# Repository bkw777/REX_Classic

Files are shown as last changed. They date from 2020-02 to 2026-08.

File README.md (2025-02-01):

# REX Classic, BKW re-spin
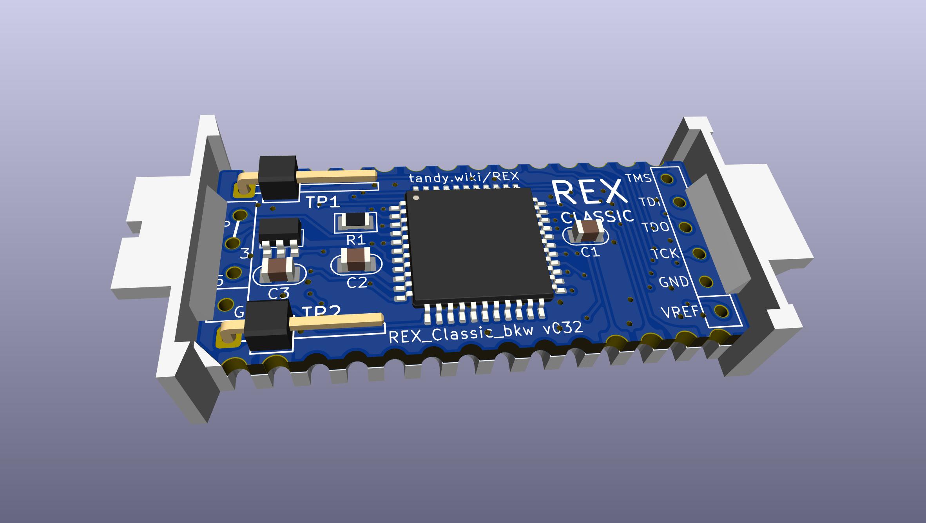
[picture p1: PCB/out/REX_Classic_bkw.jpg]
  
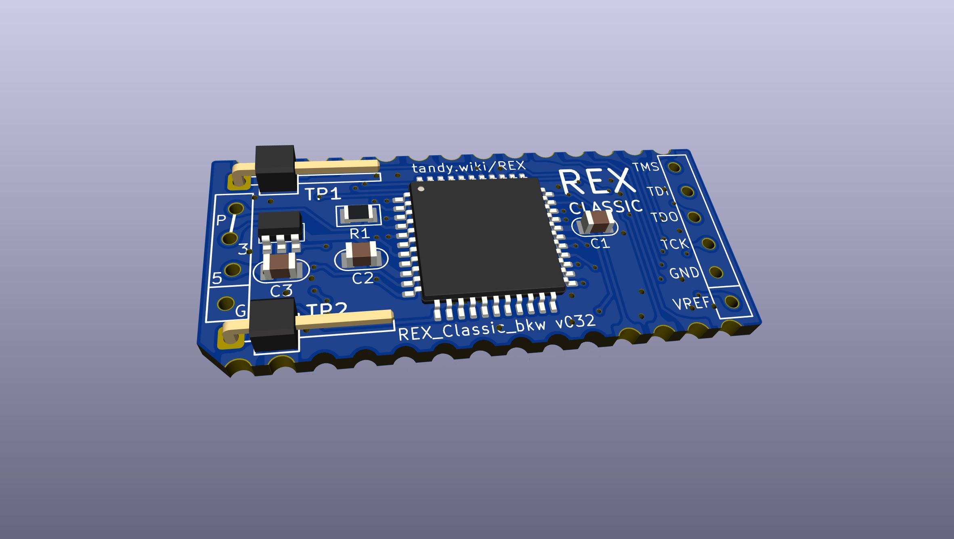
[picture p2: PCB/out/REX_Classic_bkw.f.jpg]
  
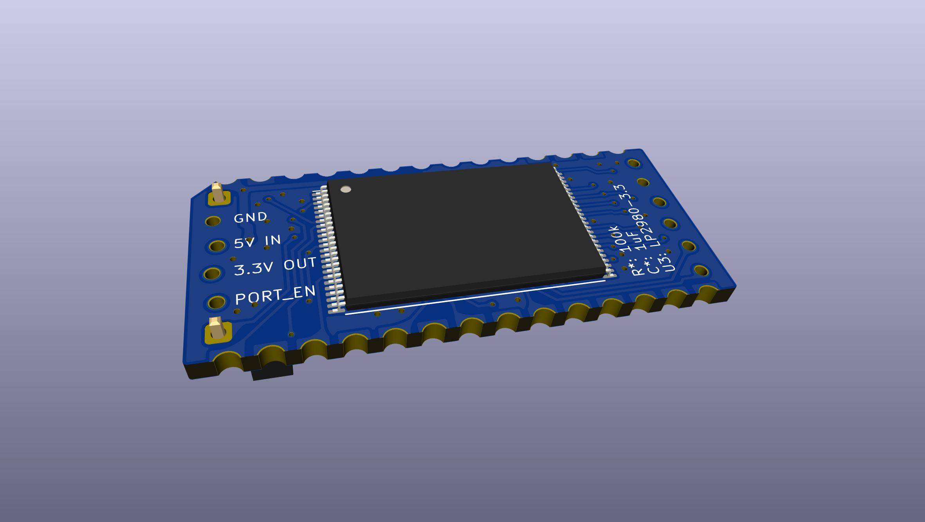
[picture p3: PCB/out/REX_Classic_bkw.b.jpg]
  
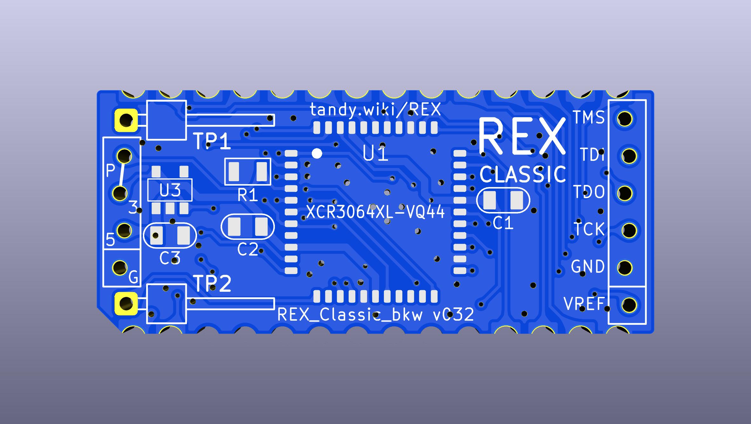
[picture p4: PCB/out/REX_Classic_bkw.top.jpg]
  
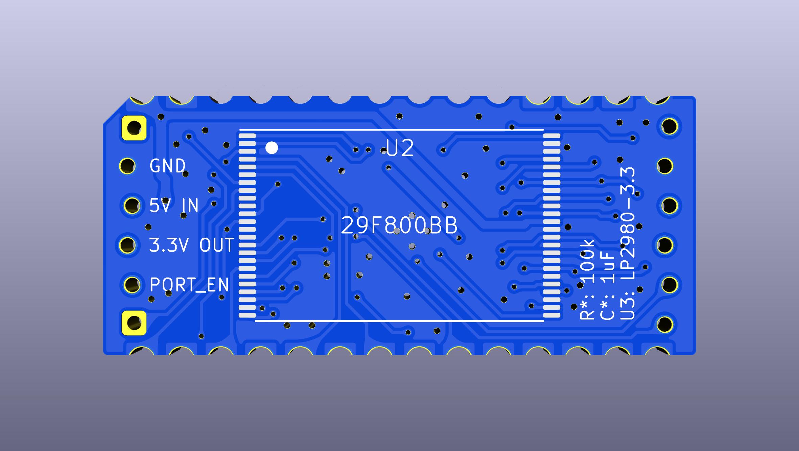
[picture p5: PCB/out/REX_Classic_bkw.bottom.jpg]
  
  

### Directions
http://tandy.wiki/REX

Gerbers & cpld bitstream in [releases](../../releases/latest).

BOM: [DigiKey](https://www.digikey.com/short/zwwvvr2j)  
PCB & Carrier: [PCBWAY](https://www.pcbway.com/project/shareproject/REX_Classic__BKW_re_spin.html)

Ordering tips for the pcb & carrier:  
* on PCBWAY manually change the min tracks/spaces to 6mil/6mil
* For gold contacts, select ENIG copper finish
* For the carrier select material Nylon, process SLS
* PCBWAY is more expensive, especially for ENIG, and they don't have the best print option for the carrier.
  Elecrow is cheaper for ENIG, and their "High Strength Nylon" option for 3d printing is actually black nylon printed by MJF, which is the nicest for this.
  It's just that on Elecrow you have to upload the gerber zip and carrier stl from [releases](../../releases/latest), there is no pre-configured buy page.

Carrier cad source: https://github.com/bkw777/Molex78802_Module (PCB_28 variant)

### Original REX design is by Steven Adolph
http://bitchin100.com/wiki/index.php?title=REX  
http://www.club100.org/memfiles/index.php?direction=0&order=&directory=Steve%20Adolph

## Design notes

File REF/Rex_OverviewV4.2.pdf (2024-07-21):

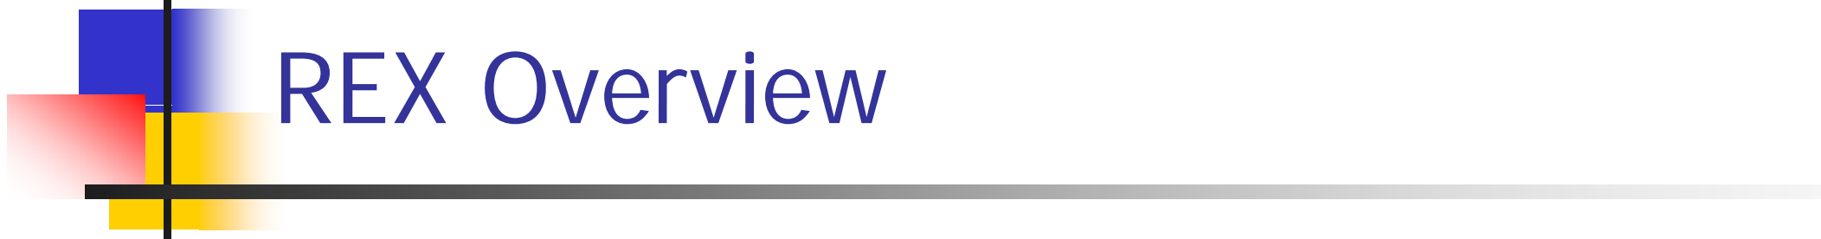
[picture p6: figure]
REX Overview

Initial Release
Steve Adolph
Oct 2008

## What is REX?

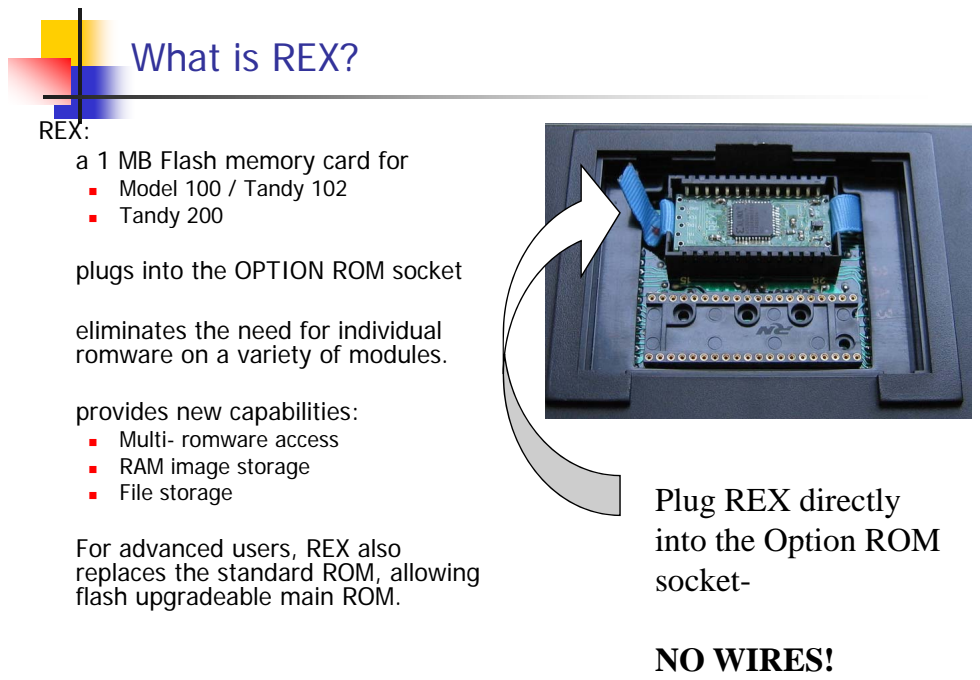
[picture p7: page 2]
Model 100 / Tandy 102; Tandy 200; - romware access; RAM image storage; File storage; For advanced users, REX also; into the Option ROM; socket-; NO WIRES!

REX:
a 1 MB Flash memory card for
plugs into the OPTION ROM socket

eliminates the need for individual
romware on a variety of modules.
provides new capabilities:
replaces the standard ROM, allowing
flash upgradeable main ROM.

Plug REX directly

## How it works

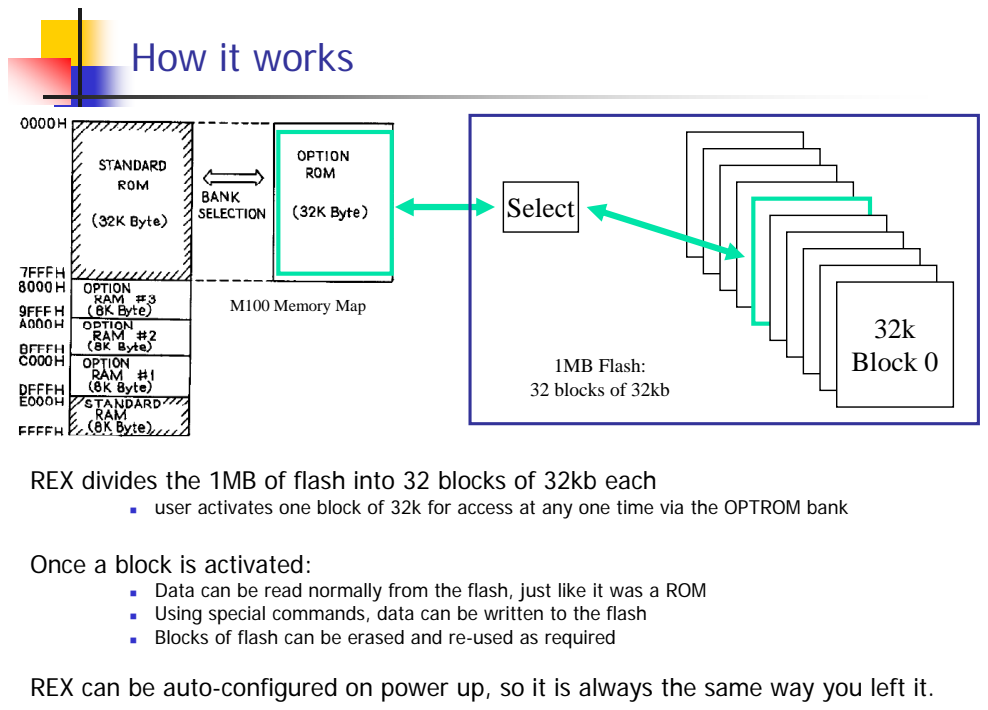
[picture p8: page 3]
Select; M100 Memory Map; 1MB Flash:; Block 0; 32 blocks of 32kb; user activates one block of 32k for access at any one time via the OPTROM bank; Data can be read normally from the flash, just like it was a ROM; Using special commands, data can be written to the flash; Blocks of flash can be erased and re-used as required

REX divides the 1MB of flash into 32 blocks of 32kb each

Once a block is activated:

REX can be auto-configured on power up, so it is always the same way you left it.

## REX Architecture

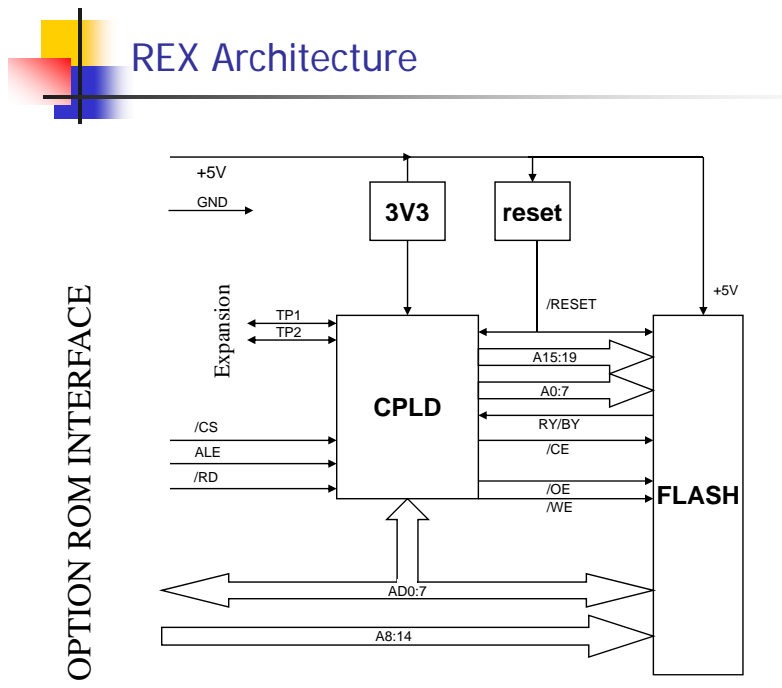
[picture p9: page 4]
+5V reset GND; /RESET; CE TP1 nsion; TERFATP2 Expa; ROM I; PTION

A15:19 A0:7 CPLD /CS RY/BY

/CE ALE /RD /OE /WE | FLASH

## REX Physical Specifications

Physical Dimensions
To fit within OPTION ROM socket

FLASH
| 1MB AM29F800B 5V FLASH
| Xilinx Coolrunner XCR3064XL-10VQ44

Power Supplies
| CPLD: LP2980 (3.3 fixed, derived from system +5V)
| FLASH: system +5V (external to REX)

Power Consumption
Negligible during reads, TBD during writes

## REX Memory Assignment

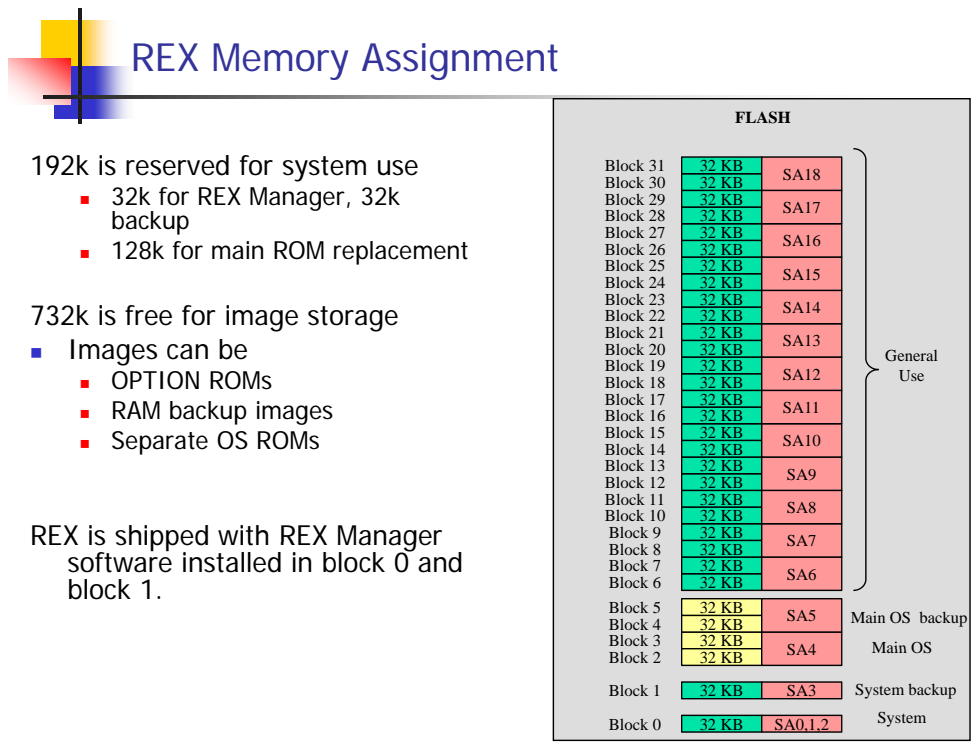
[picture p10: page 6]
32k for REX Manager, 32k; backup; Block 28; Block 29; Block 30; Block 31; FLASH

192k is reserved for system use

 128k for main ROM replacement 732k is free for ima ge stora g e | Block 27 32 KB SA16 Block 26 32 KB Block 25 32 KB SA15 Block 24 32 KB Block 23 32 KB SA14 Block 22 32 KB

 Images can be  OPTION ROMs  RAM backup images  Sepa rate OS ROMs | Bloc k 21 32 KB SA13 Block 20 32 KB General Block 19 32 KB SA12 Use Block 18 32 KB Block 17 32 KB SA11 Block 16 32 KB Block 15 32 KB

REX is shipped with REX Manager | SA10 Block 14 32 KB Block 13 32 KB SA9 Block 12 32 KB Block 11 32 KB SA8 Block 10 32 KB 32 KB Block 9 SA7 SA7

software installed in block 0 and block 1. | Block 8 32 KB Block 7 32 KB SA6 Block 6 32 KB Block 5 32 KB SA5 Main OS backup Block 4 32 KB Block 3 32 KB SA4 Main OS Main OS SA4

Block 2 32 KB System backup Block 1 32 KB SA3 System Block 0 32 KB SA0,1,2

## REX2 Architecture

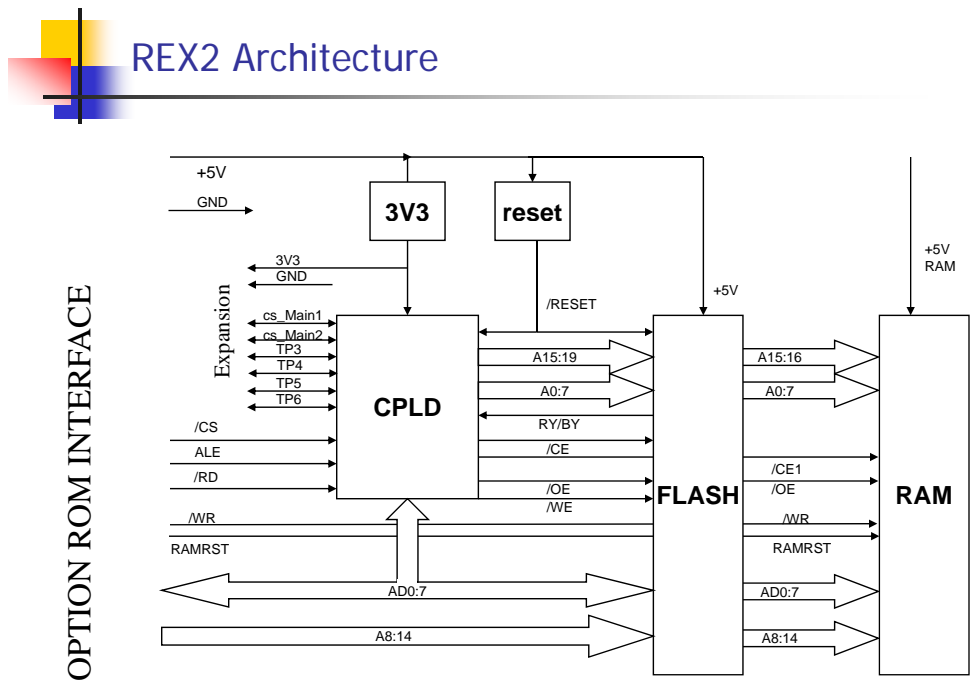
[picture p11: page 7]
+5V reset GND; /RESET; +5V RAM; cs_Main1; 3V3 GND; nsion; TERFATP3 TP4 cs_Main2 TP5 TP6; Expan

A15:19 A0:7 CPLD /CS RY/BY | A15:16 A0:7

ROM IN RAM /WR /WR

/CE ALE /RD /OE /WE | /CE1 /OE FLASH

PTION RAMRST RAMRST

## REX2 Physical Specifications

Physical Dimensions
| To fit within option rom socket
| 1MB AM29F800B 5V FLASH

CPLD
Xilinx Coolrunner XCR3064XL-10VQ44

RAM (REX2 only)
Toshiba TC551001 5V SRAM

Power Supplies
CPLD: LP2980 (3.3 fixed)

Power Consumption
Negligible during reads, TBD during writes

REX2 Memory Assignment | SRAM

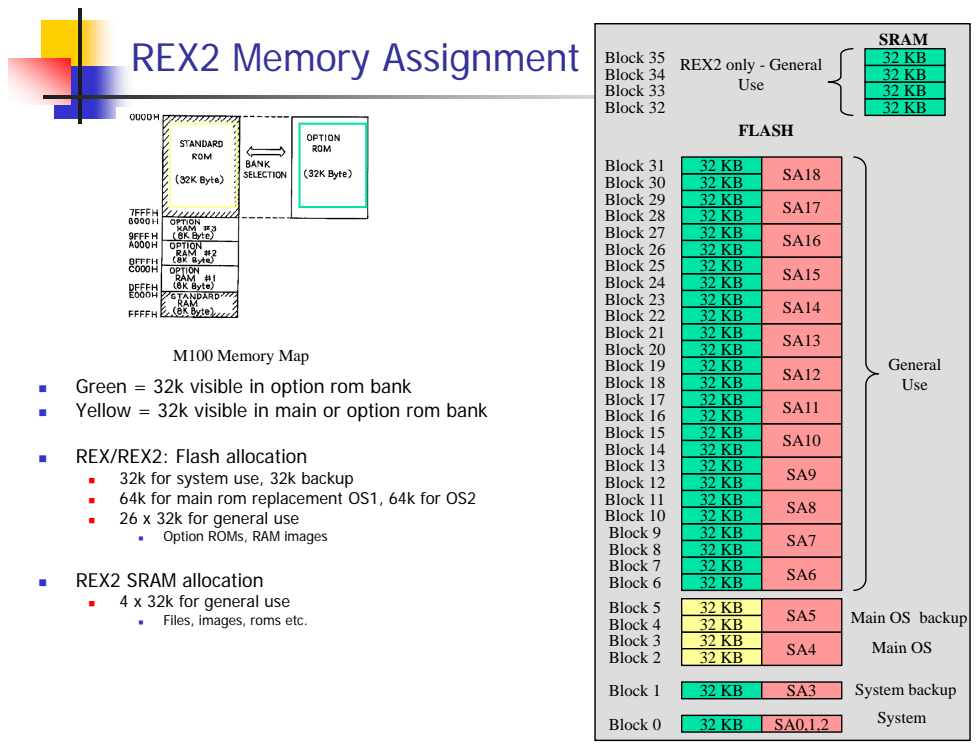
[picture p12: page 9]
Use

Block 35 REX2 only - General
Block 34
Block 33
Block 32

FLASH Block 31 32 KB SA18 Block 30 32 KB Block 29 32 KB SA17 Block 28 32 KB

Block 27 32 KB SA16 Block 26 32 KB Block 25 32 KB SA15 Block 24 32 KB Block 23 32 KB SA14 Block 22 32 KB

M100 Memory Map  Green = 32k visible in option rom bank  Yellow = 32k visible in main or option rom bank | Bloc k 21 32 KB SA13 Block 20 32 KB General Block 19 32 KB SA12 Block 18 32 KB Use Block 17 32 KB SA11 Block 16 32 KB Block 15 32 KB

 REX/REX2: Flash allocation  32k for system use, 32k backup  64k for main rom replacement OS1, 64k for OS2  26 x 32k for general use ges  O ption ROMs, RAM ima | SA10 Block 14 32 KB Block 13 32 KB SA9 Block 12 32 KB Block 11 32 KB SA8 Block 10 32 KB Block 9 32 KB SA7 SA7

 REX2 SRAM allocation  4 x 32k for general use  Files, images, roms etc. | Block 8 32 KB Block 7 32 KB SA6 Block 6 32 KB Block 5 32 KB SA5 Main OS backup Block 4 32 KB Block 3 32 KB SA4 Main OS Main OS SA4

Block 2 32 KB System backup Block 1 32 KB SA3 System Block 0 32 KB SA0,1,2

## The ACTIVE block

What is the ACTIVE Block?
Any of the 32 blocks of flash memory can be “active” – that means that the block is currently visible in the option ROM bank.
When a block is “active”, the 32k binary image stored in that block looks exactly as if an option ROM with that image was plugged in.
In this way REX allows the user to have access to all 1MB of the flash chip

Setting or changing the ACTIVE Block:
The user can define what block is “active” IE “in use”, using the integrated REX Manager software.

POWER UP:
| When the laptop is powered up, REX defaults to block 0 always.
| Auto-activation: REX installs some special software in the laptop that
redirects the power up routines to REX Manager, which searches for the
active block and sets it up for the user on every power up , | .

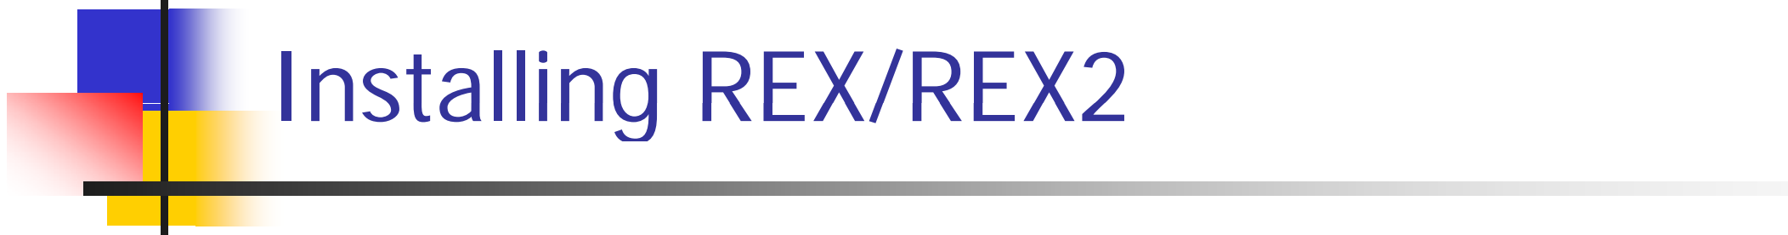
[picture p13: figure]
Installing REX/REX2

## Installing REX

REX installs in the OPTION ROM socket just like any other ROM.

Three things are supplied with REX -
| REX card
| Ribbon (used to extract REX if need be)
| Balsa spacer (used to guarantee REX seats properly in the socket Balsa spacer (used to guarantee REX seats properly in the socket

## Installing REX: Step 1

Insert balsa spacer gently GENTLY into the OPTION ROM socket. You may have to press against the springy contacts of the socket to get the spacer to sit flat against the bottom of the socket.

## Installing REX: Step 2

Lay the ribbon on top of the balsa spacer such that it is evenly centered in the socket, and the tails of the ribbon are even on both sides of the socket.

## Installing REX: Step 3

REX is placed in the ROM socket with the flash chip hidden, and the CPLD visible. You must orient REX correctly inside the socket. Look closely at the OPTROM socket, and you will see that one end of the socket has a single vertical notch in the center of one end, and the other has a dual vertical notch.

## Installing REX: Step 3

REX has a single white dash marking on the CPLD side on one end (opposite end from the row of six holes). This end (which also has 2 holes marked TP1 and TP2) must line up with the single notch of the socket, such that the white dash marking lines up with the single notch.

## Installing REX: Step 3

Once you understand how REX needs to be oriented in the socket, gently place REX into the OPTROM socket so that it is resting evenly on the springy contacts. Now, firmly press REX downward so that it evenly and flatly sits on top of the spacer and the ribbon, and all springy contacts are evenly contacting REX.

## Initializing REX

To initialize the environment, REX Manager’s initialization routine must be started. The initialization sequence is as follows-

First, REX Manager boot up software is installed.
| This software uses the timer hook to re-direct every power up to the REX Manager application
| This allows the active block to be detected and provisioned automatically
| A hidden file RXHOOK is inj ected as the first basic program
| REXMGR.BA is injected, and allows manual starting of REX Manager

Initialization from a COLD RESTART: Initialization from a COLD RESTART:
| Enter BASIC
| Type
| CALL 63012 <enter>
| You will be directed to the initialization routine

Re-initializing the environment (if needed):
| Everytime REX Manager runs it verifies that it is properly installed Everytime REX Manager runs, it verifies that it is properly installed, and it re-installs all files and the timer hook settings needed.

## Starting REX Manager

Starting REX Manager:
| Load and run the basic program REXMGR.BA
| You will be directed to REX Manager

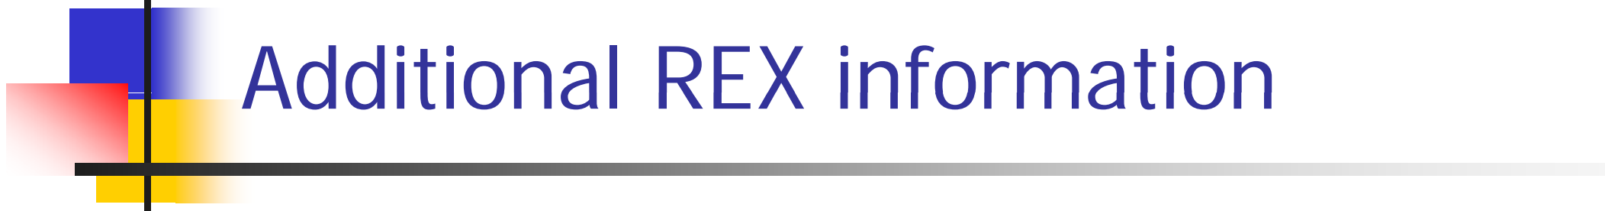
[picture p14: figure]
Additional REX information

## REX Registers

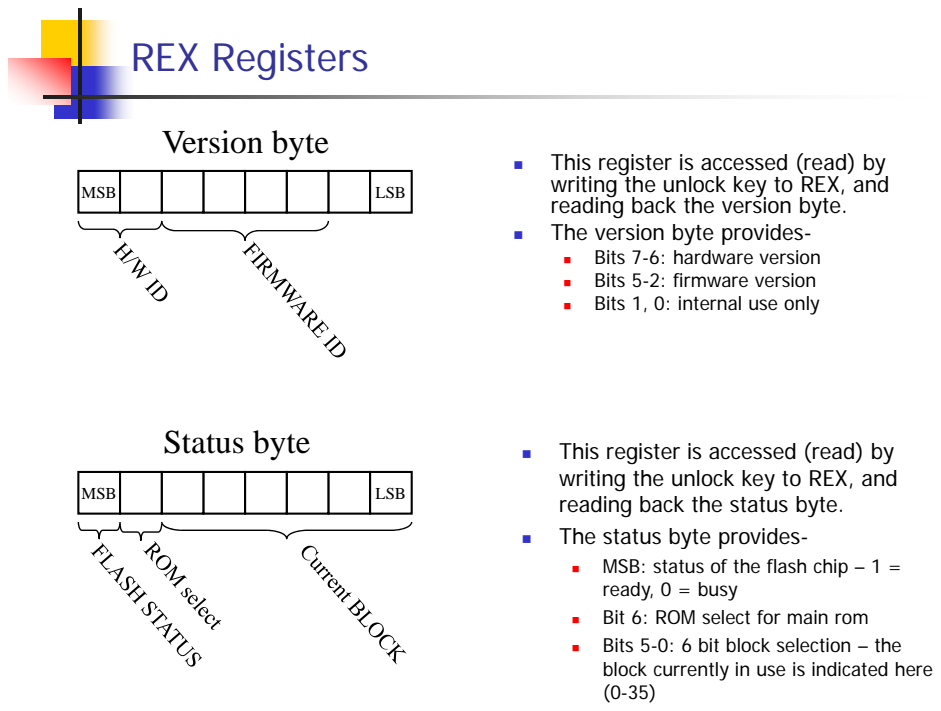
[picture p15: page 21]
This register is accessed (read) by; reading back the version byte. MSB; LSB; Version byte; The version byte provides-; Bits 7-6: hardware version; Bits 5-2: firmware version; Bits 1, 0: internal use only; MSB; The status byte provides-; Status byte; MSB: status of the flash chip – 1 =; Bit 6: ROM select for main rom; Bits 5-0: 6 bit block selection – the

writing the unlock key to REX, and

reading back the status byte.
ready, 0 = busy
block currently in use is indicated here

## REX state machine

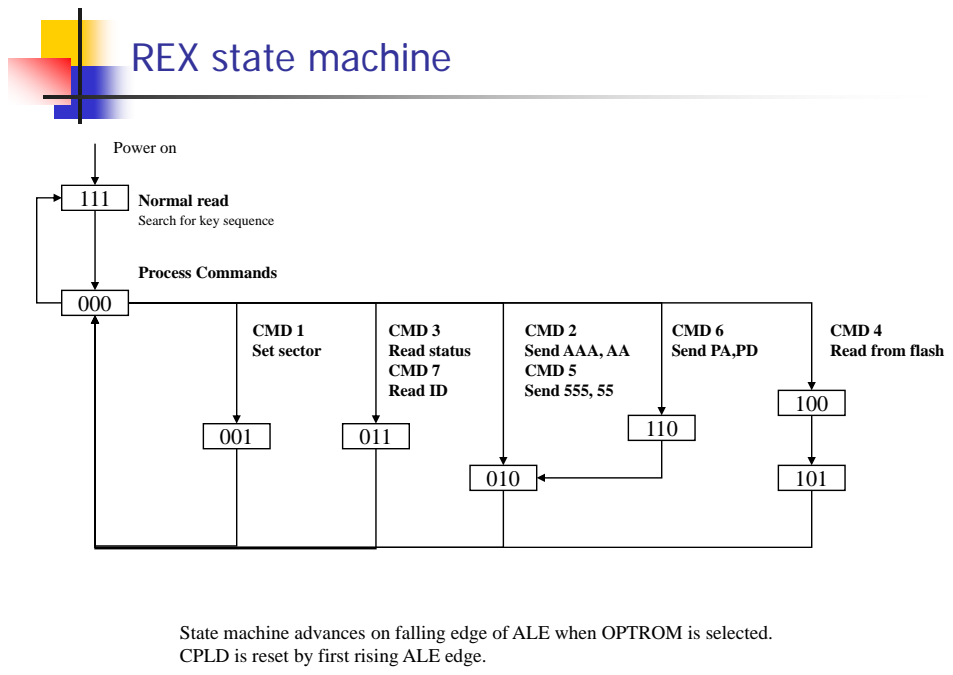
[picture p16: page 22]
Power on; CMD 1; Process Commands; CMD 3; CMD 2; CMD 6; CMD 4; CMD 1 Set sector; CMD 3 Read status CMD 7 Read ID

Normal read
Search for key sequence

CMD 2
Send AAA, AA
CMD 5
Send 555, 55

CMD 6
Send PA,PD

CMD 4
Read from flash

State machine advances on falling edge of ALE when OPTROM is selected.
CPLD is reset by first rising ALE edge.

## REX Manager software

REX has it’s own management software built in – REX Manager
| This software is provided as a option rom, and is loaded into the default power up block, block 0.
| It is also backed up into block 1.
| REX Mana ger comes in 2 versions – M100/T102 and T200 – they are not interchangeable, however one may reprogram the software to suit.

REX Manager (Release 4.2) supports
| Select – user identifies a block to process
| Activate – user identifies a block to be “in use”
| Copy – copy an image from “selected” block to another block
| Erase – erases the “selected” block
| Program – programs the “selected” block from a 32k binary file stored on TPDD
| Name – assign a name to the “selected” block

REX Mana

g er kee

ps track of the “active” block in a 1kb directory, and the names of all the blocks in another 3kb directory.
| Directories are stored in block 0, backed up in block 1.
| 1000 active block assignments can be made before the directory needs to be rebuilt
| 368 block name assignmen ts can be ma de b e fore the directory nee ds to be rebuilt
| Directory rebuilding is an automatic function, transparent to the user.

## Flash organization

The AM29F800B flash chip is designed with 19 SECTORS
A sector is defined as an independent, erasable area within the flash
The entire chip can be erased, or a single sector can be erased sector can be erased
| There are 4 small sectors
| SA0 – 16 kbytes
| SA1 – 8 kbytes
| SA2 – 8 kbytes
| SA3 – 32 kbytes
| The remaining sectors are 64 kbytes
| This poses a challenge to the M100 user.
A rom image is typically 32kb, but the sector size is 64 kb. So, erasing one 32k block requires erasing another adjacent block requires erasing another adjacent 32k block, and re-writing the contents later.
| In general, to program a rom, one must
| Copy the other ½ of the sector to
another sector
| Erase the sector
| Program the new rom image to half of
the sector
Reprogram the other half of the sector

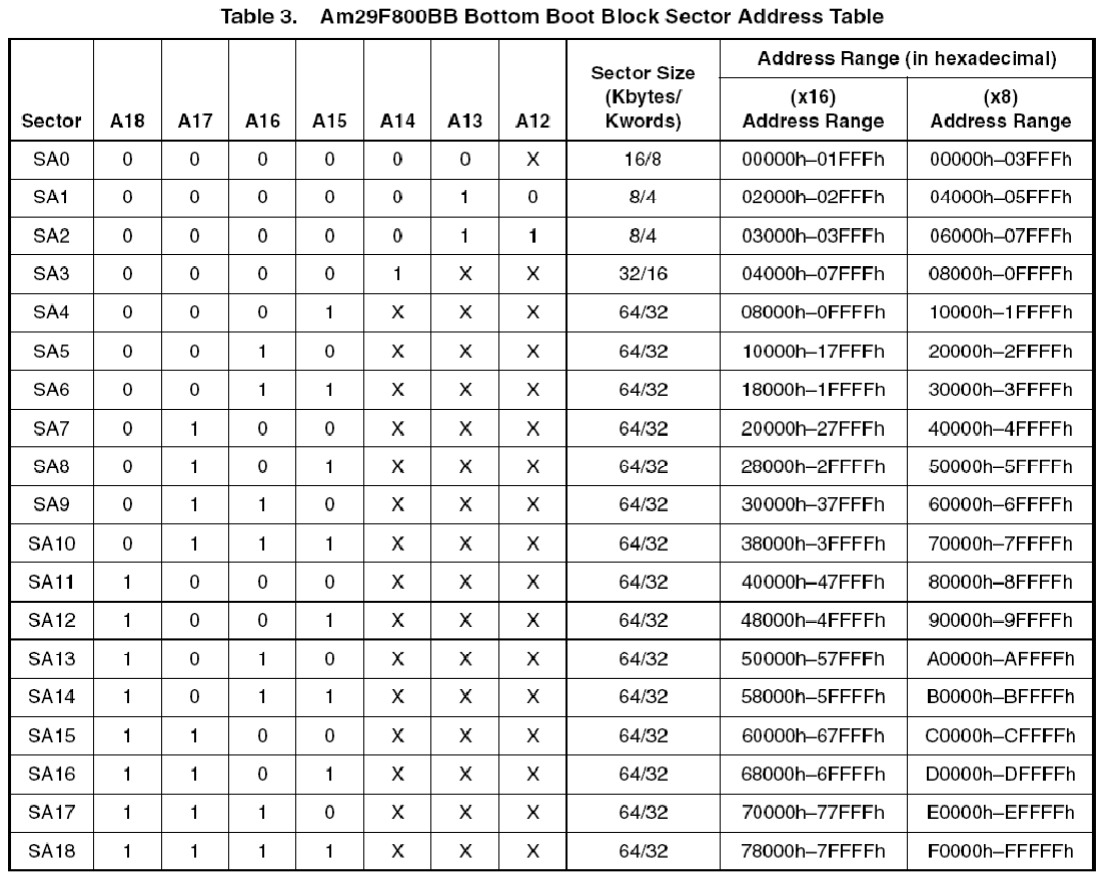
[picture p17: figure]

SECTOR == memory regions defined in flash device

BLOCK == a 32 kbyte region mapped into the option rom memory usable by the laptop rom memory, usable by the laptop

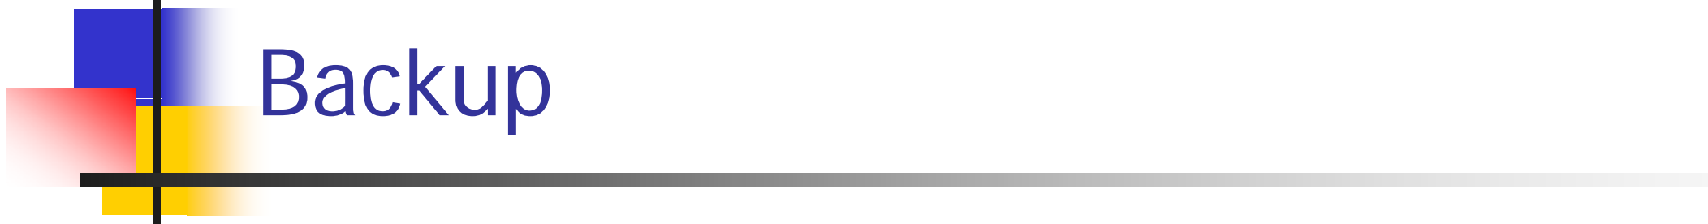
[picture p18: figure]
Backup

## REX vs. REX2

REX (available now) has a single 1 MB flash chip.

## REX2 (not available yet) incorporates a 128 KB

static RAM chip as well as the 1MB flash chip.
This increases the # of blocks from 32 to 36 (blocks 33-36 are SRAM).

## Benefits:

Additional memory for general use
Supports all-ram operation (CP/M!) Supports ram based file storage.

## SRAM access in REX2 requires installation of 3 additional wires

Vram, /WR and RAMRST

## REX Installation Levels

## LEVEL 1: Wire Free basic installation

| Standard installation, all base features
| Simple plug an

d play install
Valid for all firmware codes

## LEVEL 2: ROM Replacement

| Allows the main rom to be provided by REX
| Re

q uires 1

(M100/T102) or 2

(T200) wires to be installed
| The original main rom(s) must be removed or disabled
| On M100/T200, the rom chip(s) can simply be unplugged
| On T102, the rom chip must be removed or disabled

## REX2 Overview

REX2 is a FLASH card that plugs into the option rom socket on M100, T102 and T200 laptops.

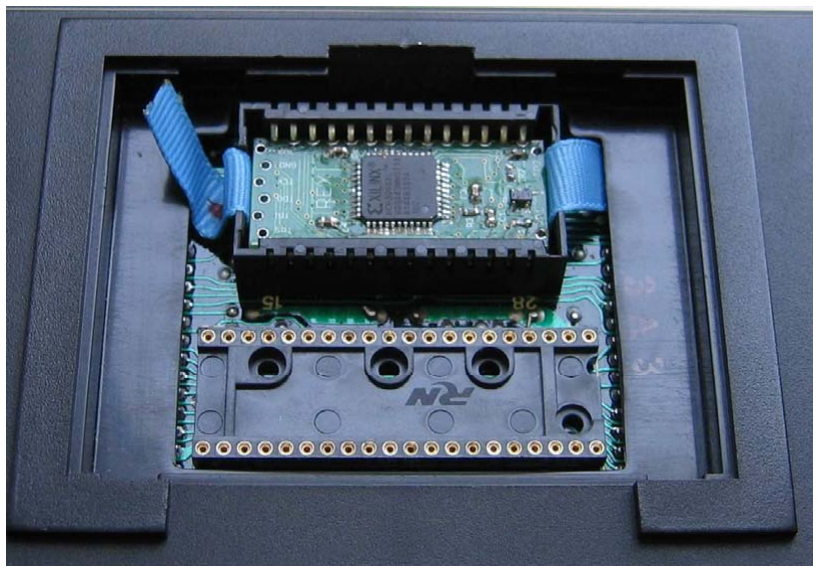
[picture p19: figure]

This upgrade provides Memory expansion via the option ROM bank
| 1 Mb of flash memory 1 Mb of flash memory
| REX2 only: 128 kb of SRAM
| Memory used for
| multiple rom storage
| Flash File storage
| System image backups System image backups
| *Upgradeable main rom
| *Rom development
| *Ram file storage

REX2 also provides an expansion capability
Power/ground + 4 unused I/O

* Level 2 and 3 installation features

## REX Installation Requirements

Model | Level 1 install: Base features | Level 2 install: Rom Replacement | Wires needed
REX | | | No wires needed
REX | | | 1 (M100/T102) 2 (T200)

LEVEL 1: Wire Free basic
installation

LEVEL 2: ROM Replacement
REX provides the main ROMs Two OS images are supported Standard installation, all base features
| Simple plug and play install
| Two OS images are supported
| Requires some hardware modification
| The original main ROM(s) must be
removed or disabled
| - unp lu

g the ROM
| T200 - unplug the ROMs
| T102 - the ROM must be removed or
disabled

## REX Versions

Version 1: REX
| has a CPLD and a flash chip for a total of 2 ICs
| Hardware ID = 00

Version 2: REX2
| has a CPLD, a flash chip, and an SRAM chip for a total of 3 ICs
| hardware ID = 01

Each REX has a CPLD firmware load
| Firmware ID is a 6 bit value
| Readable from the REX version byte Readable from the REX version byte
| Firmware is not upgradable by the user, but it can be upgraded by returning it.

Can be used in either M100/T102 or T200
| Each REX can be shipped with a software load for either M100/T102 or T200
| The software load contains all the utilities and functions needed to operate REX.
| User can change or upgrade this load by using a special utility

## ROM Replacement

If level 2 installation is done, a valid ROM image MUST be present in block 2/3 to boot the machine
| If this block is somehow corrupted, then REX cannot boot the machine.
| There is no emergency safeguard to having a bad image burned
| Once the process to update block 2/3 is started, there is no way to
detect and take action for a bad burn detect and take action for a bad burn

In the event of a corrupt OS preventing boot up, the original main rom needs to be installed again
| This amounts to reverting to a level 1 installation.
| Advanced users could install a switch and pull up inside the ROM
compartment such that the /CS signal to activate the main rom is either:
| directed to REX, and the main rom CS is pulled high, or
| Directed to the main rom and open circuited to REX (REX has a pullup)
| This would allow a mechanism to safeguard against a non-booting machine.

## REX Installation Levels

## LEVEL 1: Wire Free basic installation

| Standard installation, all base features
| Sim

p le

plu

g and

pla

y install

## LEVEL 2: ROM Replacement

| Additional feature included in firmware
| Allows the main rom to be provided by REX
| Requires 1 (M100/T102) or 2 (T200) wires to be installed

The system rom must be removed or disabled
| On M100/T200, the rom chip can simply be unplugged
| On T102, the rom chip must be removed or disabled.

## LEVEL

## 3: 128kb SRAM up

## gra

d

e
| Advanced feature supported by REX2 only
| Allows SRAM to be accessed via the option rom bank

Three wires must be connected from REX2 to system board (clips provided)

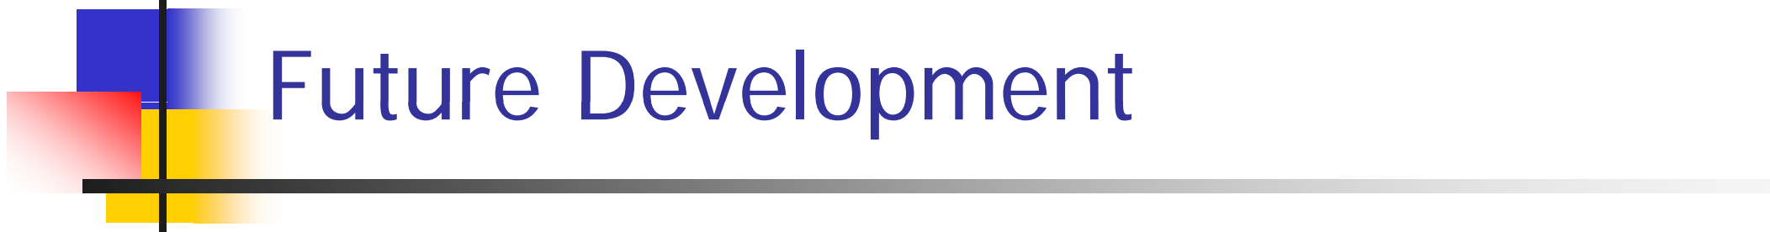
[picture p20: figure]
Future Development

## Flash File System

| Sectors SA0-SA6 are for roms
| Sectors SA7-SA18 are for files
| At least 1 sector must remain free for use as scratchpad
| This leaves 768k – 64k = 704kb as file storage
| Scratchpad allows sectors to be purged of deleted files, and may be used by rom burning routines to copy
blocks
First 1k of every sector used in the file system will be a distributed file directory and block directory
| Need 32 block directory entries, supporting 8 types of blocks
| Type 0: rom binary image block
| Type 1: ram binary image block (M100)
| Type 2: ram binary image block #1 (T200)
| Type 3: ram binary image block #2 (T200)
| Type 4: ram binary image block #3 (T200)
| Type 5: file storage block type 1 (contains directory)
| Type 6: file storage block type 2 (contains only files)
| Type 7: unused/scratchpad
| Byte 00
| Incates sector status
| FF = unused, scratch pad possible
| 00 = in use for file system
| Files will be stored on a 1kb record size similar to RAMPAC
| Files must be contained within a single sector
| This limits file sizes to 32 kb max
| Up to 63 files may be stored in one sector – 693 files max stored in REX
| Directories occupy a directory entry, so directories reduce the # of files per sector

## Flash File System

| Directory entries
| Can be either file names or directory names
| Up to 255 file directories can be named, nesting is supported
| each directory entry is 14 bytes long each directory entry is 14 bytes long
| Byte 0 = type; 0=file, 01-FF = directory number for this record (if not a file)
| Byte 1 = directory membership = number from 0 to FF
| Byte 2 = file type descriptor
| Byte 3,4 = file length
| Bytes 5,6 = undefined
| Bytes 7-12 = filename or directory name
| Bytes 13-14 = extension

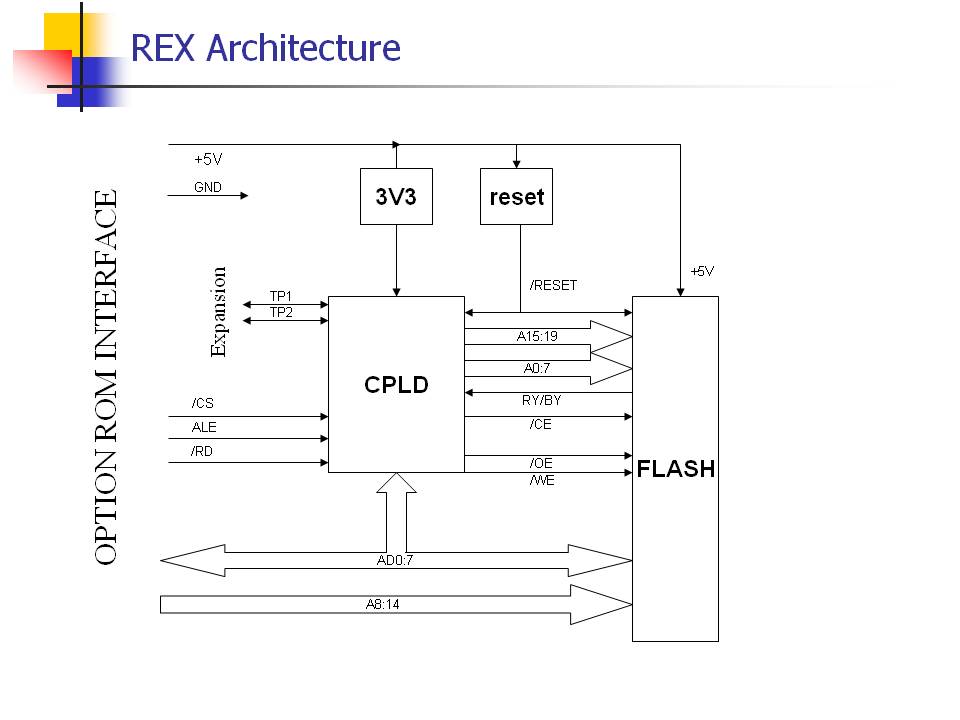
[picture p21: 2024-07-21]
REF/Rex_architecture.jpg

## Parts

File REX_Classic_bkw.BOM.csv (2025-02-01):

Index | Quantity | Part Number | Manufacturer Part Number | Description | Customer Reference | Available | Backorder | Unit Price | Extended Price USD
1 | 1 | 122-1469-ND | XCR3064XL-10VQG44I | IC CPLD 64MC 9.1NS 44VQFP | U1 | 1 | 0 | 12.59000 | 12.59
2 | 10 | A130144CT-ND | CRGCQ0805J47K | RES 47K OHM 5% 1/8W 0805 |  | 10 | 0 | 0.02700 | 0.27
3 | 10 | 399-8001-1-ND | C0805C105J4RACTU | CAP CER 1UF 16V X7R 0805 | C1 | 10 | 0 | 0.18400 | 1.84
4 | 1 | LP2980AIM5X-3.3/NOPBCT-ND | LP2980AIM5X-3.3/NOPB | IC REG LINEAR 3.3V 50MA SOT23-5 | U3 | 1 | 0 | 0.66000 | 0.66
5 | 1 | 1450-M29F800FB5AN6E2-ND | M29F800FB5AN6E2 | IC FLASH 8MBIT PARALLEL 48TSOP I | U2 | 1 | 0 | 4.32000 | 4.32
6 | 1 | 10129379-902002BLF-ND | 10129379-902002BLF | CONN HEADER R/A 2POS 2.54MM | TP1, TP2 | 1 | 0 | 0.10000 | 0.10

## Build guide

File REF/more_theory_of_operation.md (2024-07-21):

(ed: translated from https://bitchin100.com/wiki/index.php?title=REX_Overview)

## REX Overview

REX is a low power 1MB flash card custom designed to work with the Model T.  The challenge for REX is to be able to accomplish a "write" in a socket designed only for "reads".  An additional challenge, is to be able to control 19 address lines and 8 data lines to the flash, with a minimum amount of resources.  

A major challenge with REX, was finding a CPLD with enough I/O to manage the flash, while being small enough to fit in the socket.

## REX Architecture

The architecture of REX is shown in the illustration below.  Here we see that the CPLD (a programmable logic device, the "brains" of REX) sits between the flash chip and the option rom socket connector.  

REX manages only some of the address lines going to the flash - A15-A19, and A0-A7.  A8-A14 are provided as direct connections from the optrom socket, as are AD0-AD7.  REX intercepts the address/data bus AD0-AD7, and the system communicates with the CPLD using data sent on these lines.

Data is sent to REX on the falling edge of the ALE signal.  During this time, the address/data bus AD0-AD7 contains the lower address information for that CPU cycle.

So, in order to send data to REX, the data is sent as the bottom 8 bits of the ADDRESS, not the DATA, during a read cycle from the option rom.

![]Rex_architecture.jpg)

REX needs to distinguish between "normal reads" to the option rom, and "control reads" to REX.  In order to tell them apart, REX listens for a sequence of 6 reads from specific memory locations.  When this key sequence is observed, REX jumps into a command mode, to allow control of REX and manipulation of the flash.

## REX State Machine

The following illustration is the REX state machine.  This heavily optimised state machine has commands to set and read the registers of REX, and to send specific sequences to the flash to allow programming and erasing of the different blocks in the flash.

The state machine has been optimised for high speed operation as well as maximum flexibility.  REX is able to program a 32k binary image in under 4 seconds.

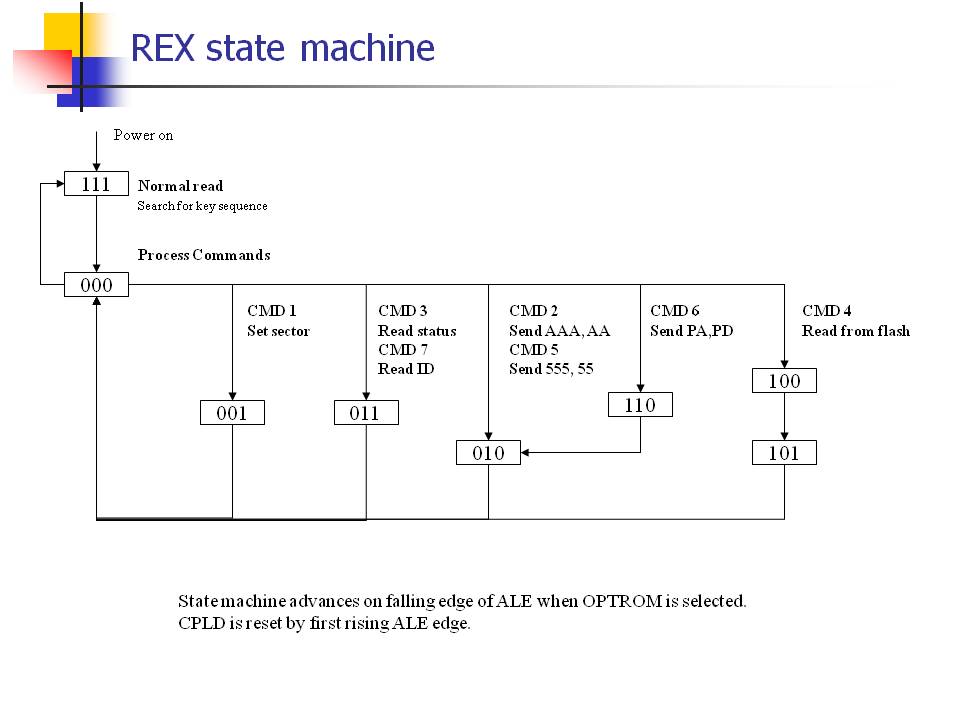
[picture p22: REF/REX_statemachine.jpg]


## REX Flash Organization

REX makes 32k blocks of flash memory visible to the Model T, and the currently visible block is selected by programming the sector register.  The flash is organised according to the following diagram.

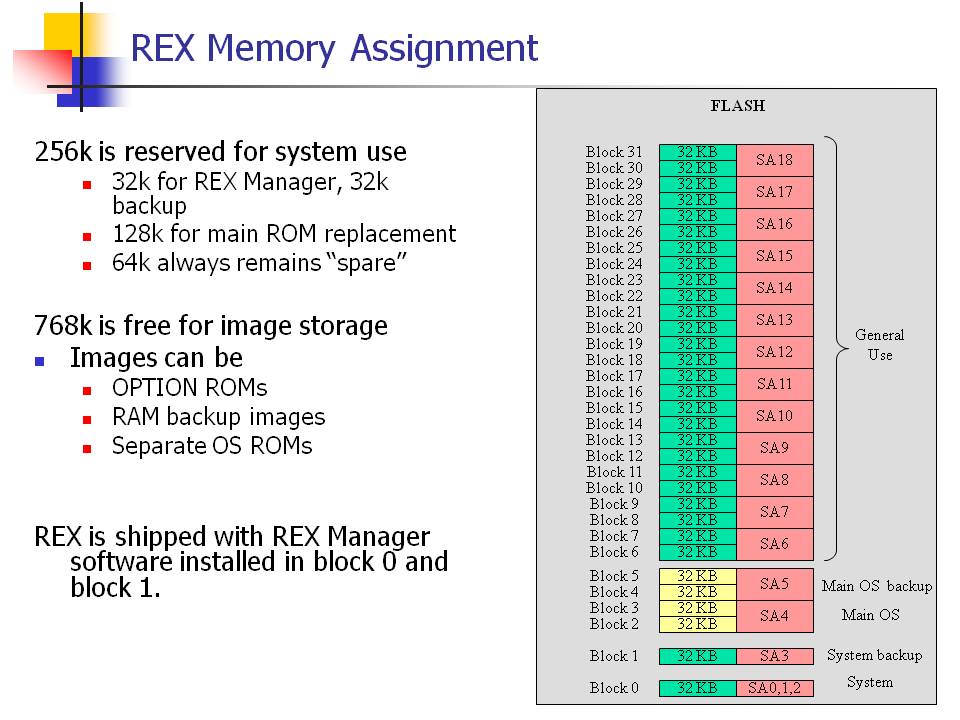
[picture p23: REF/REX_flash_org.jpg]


Here we see 6 blocks of flash, including block 0, reserved for system use, and 26 blocks are free for use to store images.

Block 0 is a special block, in that it may be erased independantly of any other block, and in 3 sections, a 16k section and 2 8k sections.  Block 1 may be erased independantly of any other block, and is a stand alone 32k block.  The remaining blocks are actually associated with a 64k sector - 2 adjacent blocks form a sector, and the entire sector must be erased at the same time.  

This poses a challenge for REX, since REX images are all 32k in size.   In general, in order to erase a block, the adjacent block must be copied to a free block first, to allow a complete erasure of the 64k sector.

128k is reserved for main rom replacement.  64k is reserved for primary main rom, and 64k is reserved for a secondary main rom.   In practice it is expected that the primary main rom gets programmed once, and left alone, since it is critical to allow reliable booting once the user unplugs the original equipment ROM.  That leaves the secondary rom for custom loads.

M100/T102 needs only 32k for each main rom, but T200 needs 40k (IE 64k).

## REX Registers

REX has 2 internal registers - the version register (read only) and the status register (read/write).  The definitions of these registers is illustrated below.

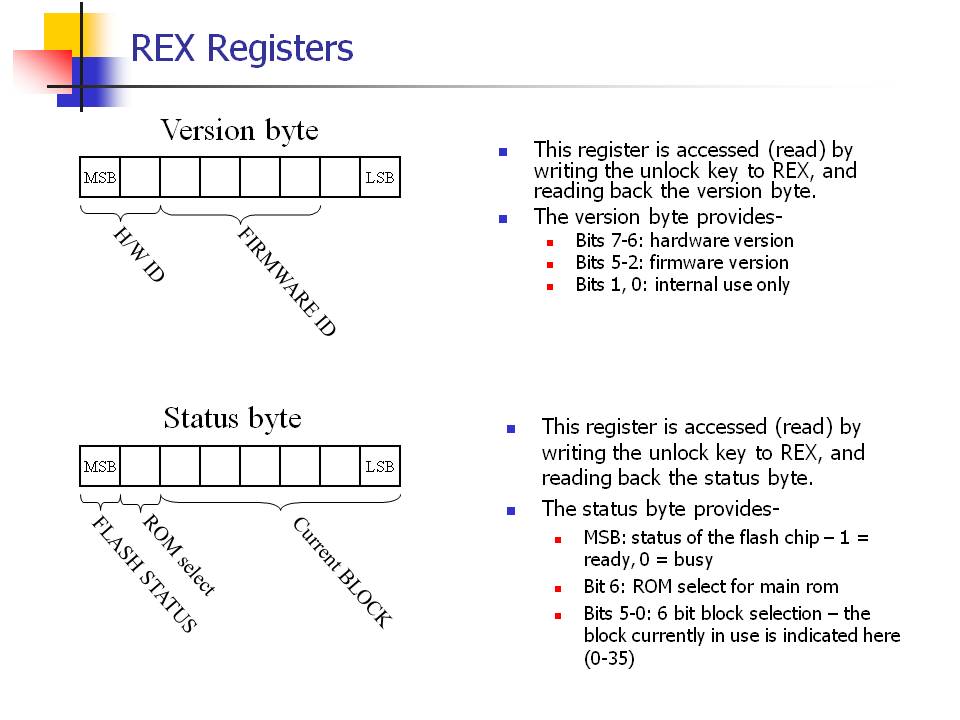
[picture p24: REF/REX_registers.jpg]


## REX Mananger Flow Chart

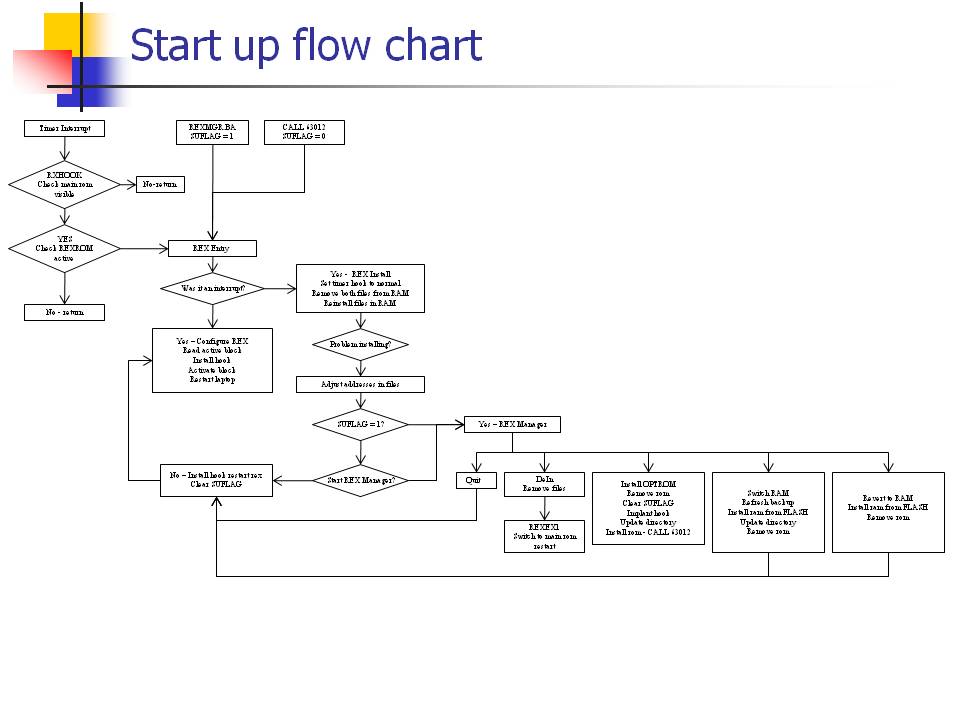
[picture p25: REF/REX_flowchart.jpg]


## Low Level REX Support Subroutines

[REX support routines ASM](rex_routines.zip)

The above file (as at release 4.6) includes all the low level REX specific subroutines for manipulating REX and the onboard FLASH. 

These routines must run in upper RAM, typically ALTLCD, because, well, REX is bank switching in the lower RAM.  Also, interrupts must always be disabled when accessing REX.  Be careful, some main ROM routines enable interrupts.

In general it is very important to understand what state REX is in.  Often I am referring to "state 111" or "state 000".  State 111 is the "normal operation" state where REX is acting like an option ROM.  Entry into state 000 occurs after the unlock key sequence is sent.   State 000 is the control state where REX can be instructed to do various things.

I would recommend that any one reading this might want to download the data sheet for the AM29F800BB flash part, and learn about how to manipulate it.

(ed: there is a copy in PCB/datasheets)

There are 4 "very low level" subroutines that are the basis for all REX operations.  These routines are called by "higher level low level subroutines".  They are

```
SNDKEY
	sends the key sequence to REX 
	entry:  none, in any state
	exit:	in state 00
	registers changed: none
SETBLOCK
	sends command 2 to REX
	entry:  a = target block
	exit:	none
	registers changed: a
WAITREADY
	sends command 3 to REX, reads status and version bytes, and returns only when flash status is ready
	entry: 	none
	exit:	b = status byte, c = version byte
	registers changed: a, hl, bc
PROGBYTE
	program a byte into the flash -  program data from b to (de)
	entry: 	de = PA, data in b
	exit:	none
	registers changed: a, hl - preseves bc and de
```

Please see the above file for examples of code that programs a block of data into REX, reading the REX status register, etc.

## The REX Communication Method

REX uses a unique approach to bi-directional communication in a read-only socket, which is 100% reliant on the architecture of the 8085.

Reads are simple - the socket is designed for Read Only.

Writes are the challenge, with the signals available.

The 8085 uses a multiplexed address and data bus, and the ALE signal is used to discriminate address from data early in the CPU cycle.  Normally address data is captured on the falling edge of ALE.  We use this fact to send data to REX embedded in the lower address byte.

REX watches the address bus for READ operations (signaled by /CS to the option rom socket), and listens to the lower byte.

To send data to REX then, one must perform a READ to the optrom socket, where the desired data is actually the lower address field.  REX is clocked from ALE, so it will respond to stimulus from the bus on the falling edge of ALE.

REX mostly ignores this data, and acts like a normal option rom, until it senses the key sequence has been sent.  When a sequence of 6 reads from addresses with specific bytes in the lower address field are seen, REX transitions from the default power up state into the command state.

The key sequence happens to be: B6 F2 34 B0 31 BF (hex).

## Power Up and RESET of REX

REX does not see the reset signal in the PC.  So, reset does not affect REX. REX is reset by power down/up.

When REX is reset, it reverts to it's power up default - state 111 and block 0 present.

If by chance the flash chip hangs with status bit 0, then power cycling the machine will also reset the FLASH to normal operation.

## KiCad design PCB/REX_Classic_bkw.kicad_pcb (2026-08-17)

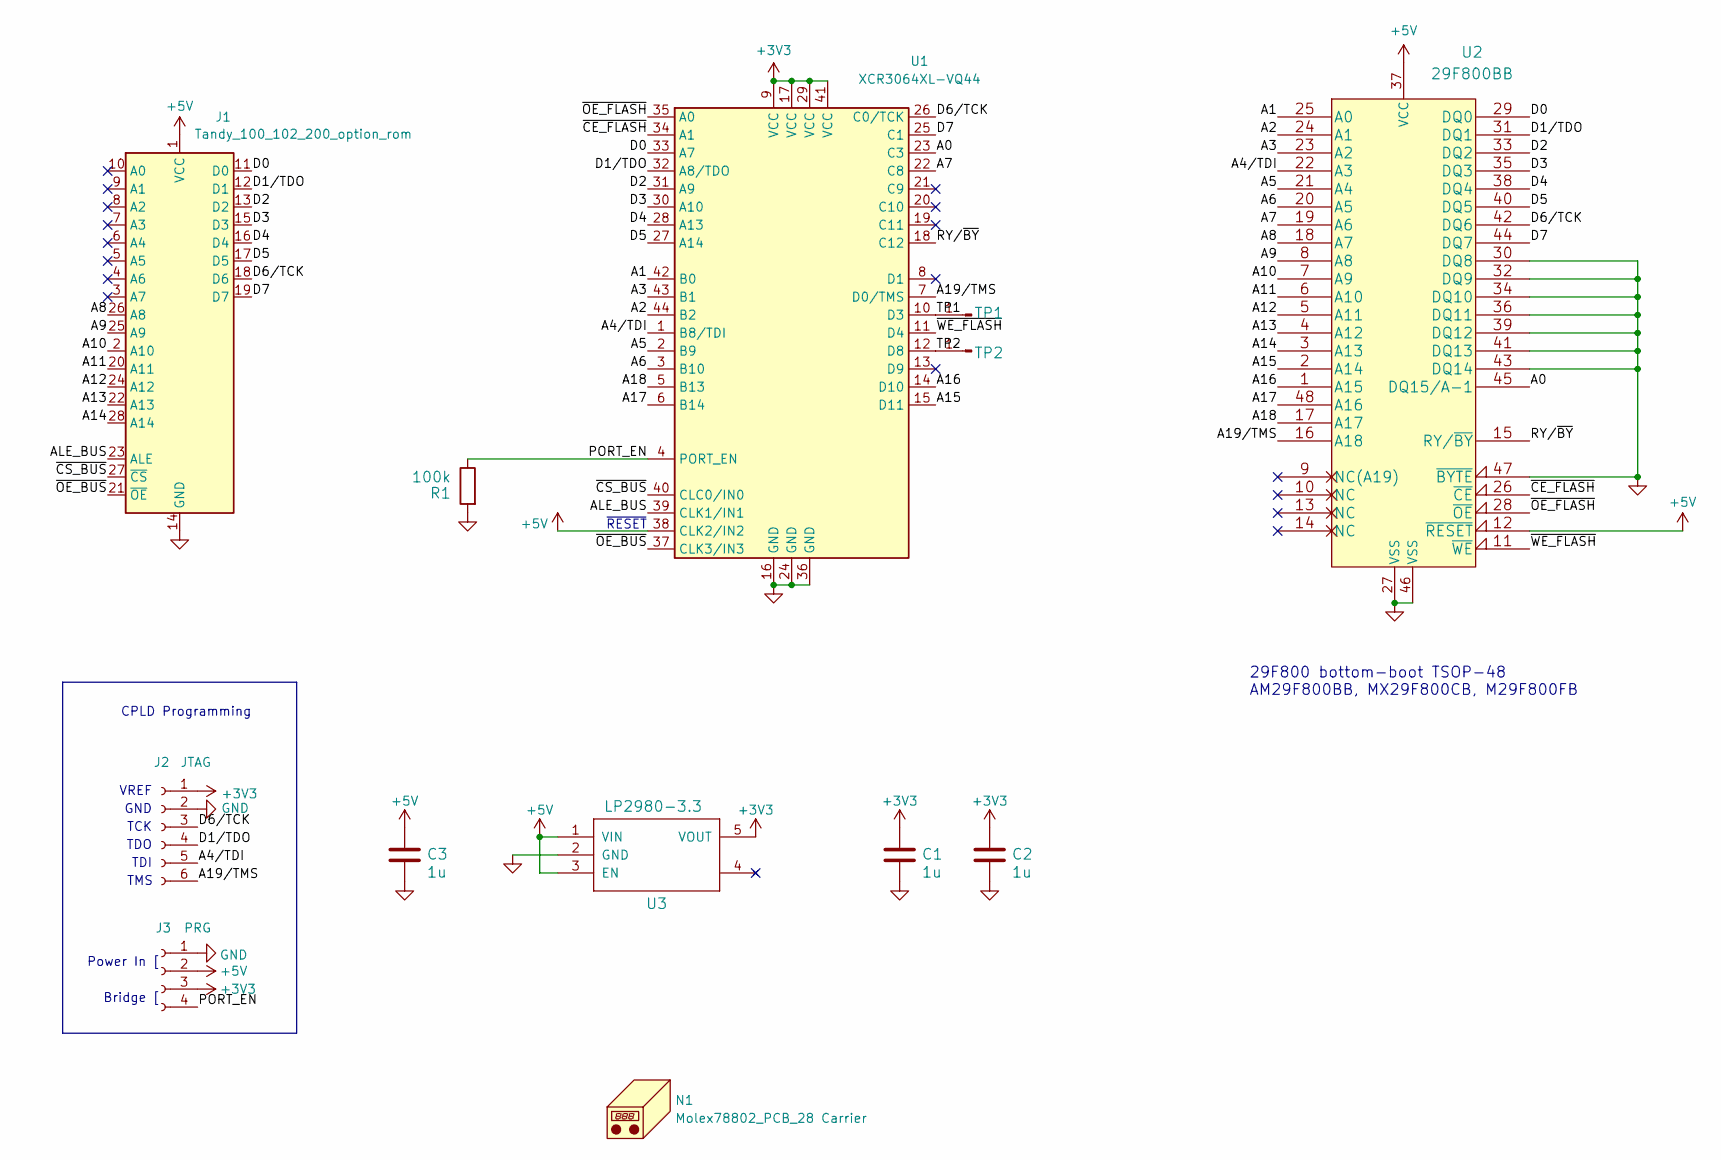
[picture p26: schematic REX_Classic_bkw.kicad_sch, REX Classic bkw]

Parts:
C1, C2, C3: 1u; C_0805
J1: Tandy_100_102_200_option_rom; Molex78802_PCB_28_REX
J2: JTAG; 1x6_pcb_socket
J3: PRG; 1x4_pcb_socket
N1: Molex78802_PCB_28 Carrier; Housing_Molex78802_PCB_28
R1: 100k; R_0805
TP1, TP2: PINHD-1X1; 1x1_pin_h
U1: XCR3064XL-VQ44; VQFP44; MPN XCR3064XL-VQ44
U2: 29F800BB; TSOP-48; MPN AM29F800BB
U3: LP2980-3.3; SOT-23-5; MPN LP2980-3.3

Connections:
+3V3: C1.1, C2.1, J2.1, J3.3, U1.9 (VCC), U1.17 (VCC), U1.29 (VCC), U1.41 (VCC), U3.5 (VOUT)
+5V: C3.1, J1.1 (VCC), J3.2, U1.38 (CLK2/IN2), U2.12 (~RESET), U2.37 (VCC), U3.1 (VIN), U3.3 (EN)
/A0: U1.23 (C3), U2.45 (DQ15/A-1)
/A1: U1.42 (B0), U2.25 (A0)
/A2: U1.44 (B2), U2.24 (A1)
/A3: U1.43 (B1), U2.23 (A2)
/A4/TDI: J2.5, U1.1 (B8/TDI), U2.22 (A3)
/A5: U1.2 (B9), U2.21 (A4)
/A6: U1.3 (B10), U2.20 (A5)
/A7: U1.22 (C8), U2.19 (A6)
/A8: J1.26 (A8), U2.18 (A7)
/A9: J1.25 (A9), U2.8 (A8)
/A10: J1.2 (A10), U2.7 (A9)
/A11: J1.20 (A11), U2.6 (A10)
/A12: J1.24 (A12), U2.5 (A11)
/A13: J1.22 (A13), U2.4 (A12)
/A14: J1.28 (A14), U2.3 (A13)
/A15: U1.15 (D11), U2.2 (A14)
/A16: U1.14 (D10), U2.1 (A15)
/A17: U1.6 (B14), U2.48 (A16)
/A18: U1.5 (B13), U2.17 (A17)
/A19/TMS: J2.6, U1.7 (D0/TMS), U2.16 (A18)
/ALE_BUS: J1.23 (ALE), U1.39 (CLK1/IN1)
/D0: J1.11 (D0), U1.33 (A7), U2.29 (DQ0)
/D1/TDO: J1.12 (D1), J2.4, U1.32 (A8/TDO), U2.31 (DQ1)
/D2: J1.13 (D2), U1.31 (A9), U2.33 (DQ2)
/D3: J1.15 (D3), U1.30 (A10), U2.35 (DQ3)
/D4: J1.16 (D4), U1.28 (A13), U2.38 (DQ4)
/D5: J1.17 (D5), U1.27 (A14), U2.40 (DQ5)
/D6/TCK: J1.18 (D6), J2.3, U1.26 (C0/TCK), U2.42 (DQ6)
/D7: J1.19 (D7), U1.25 (C1), U2.44 (DQ7)
/PORT_EN: J3.4, R1.1, U1.4 (PORT_EN)
/RY/~BY: U1.18 (C12), U2.15 (RY/~BY)
/TP1: TP1.1, U1.10 (D3)
/TP2: TP2.1, U1.12 (D8)
/~CE_FLASH: U1.34 (A1), U2.26 (~CE)
/~CS_BUS: J1.27 (~CS), U1.40 (CLC0/IN0)
/~OE_BUS: J1.21 (~OE), U1.37 (CLK3/IN3)
/~OE_FLASH: U1.35 (A0), U2.28 (~OE)
/~WE_FLASH: U1.11 (D4), U2.11 (~WE)
GND: C1.2, C2.2, C3.2, J1.14 (GND), J2.2, J3.1, R1.2, U1.16 (GND), U1.24 (GND), U1.36 (GND), U2.27 (VSS), U2.30 (DQ8), U2.32 (DQ9), U2.34 (DQ10), U2.36 (DQ11), U2.39 (DQ12), U2.41 (DQ13), U2.43 (DQ14), U2.46 (VSS), U2.47 (~BYTE), U3.2 (GND)

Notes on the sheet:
29F800 bottom-boot TSOP-48 AM29F800BB, MX29F800CB, M29F800FB
Power In [
TDI
TMS
CPLD Programming
GND
VREF
TCK
TDO
Bridge [
~{RESET}

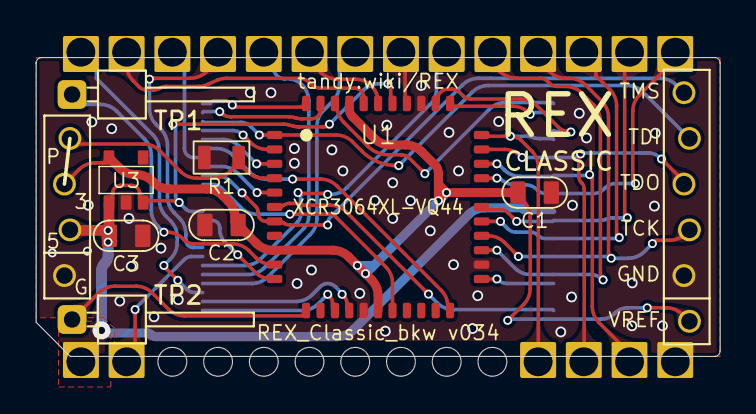
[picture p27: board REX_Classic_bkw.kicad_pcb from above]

Board: 2 copper layers, 38.0 x 16.6 mm, 13 parts (1 on the bottom side), 41 nets.

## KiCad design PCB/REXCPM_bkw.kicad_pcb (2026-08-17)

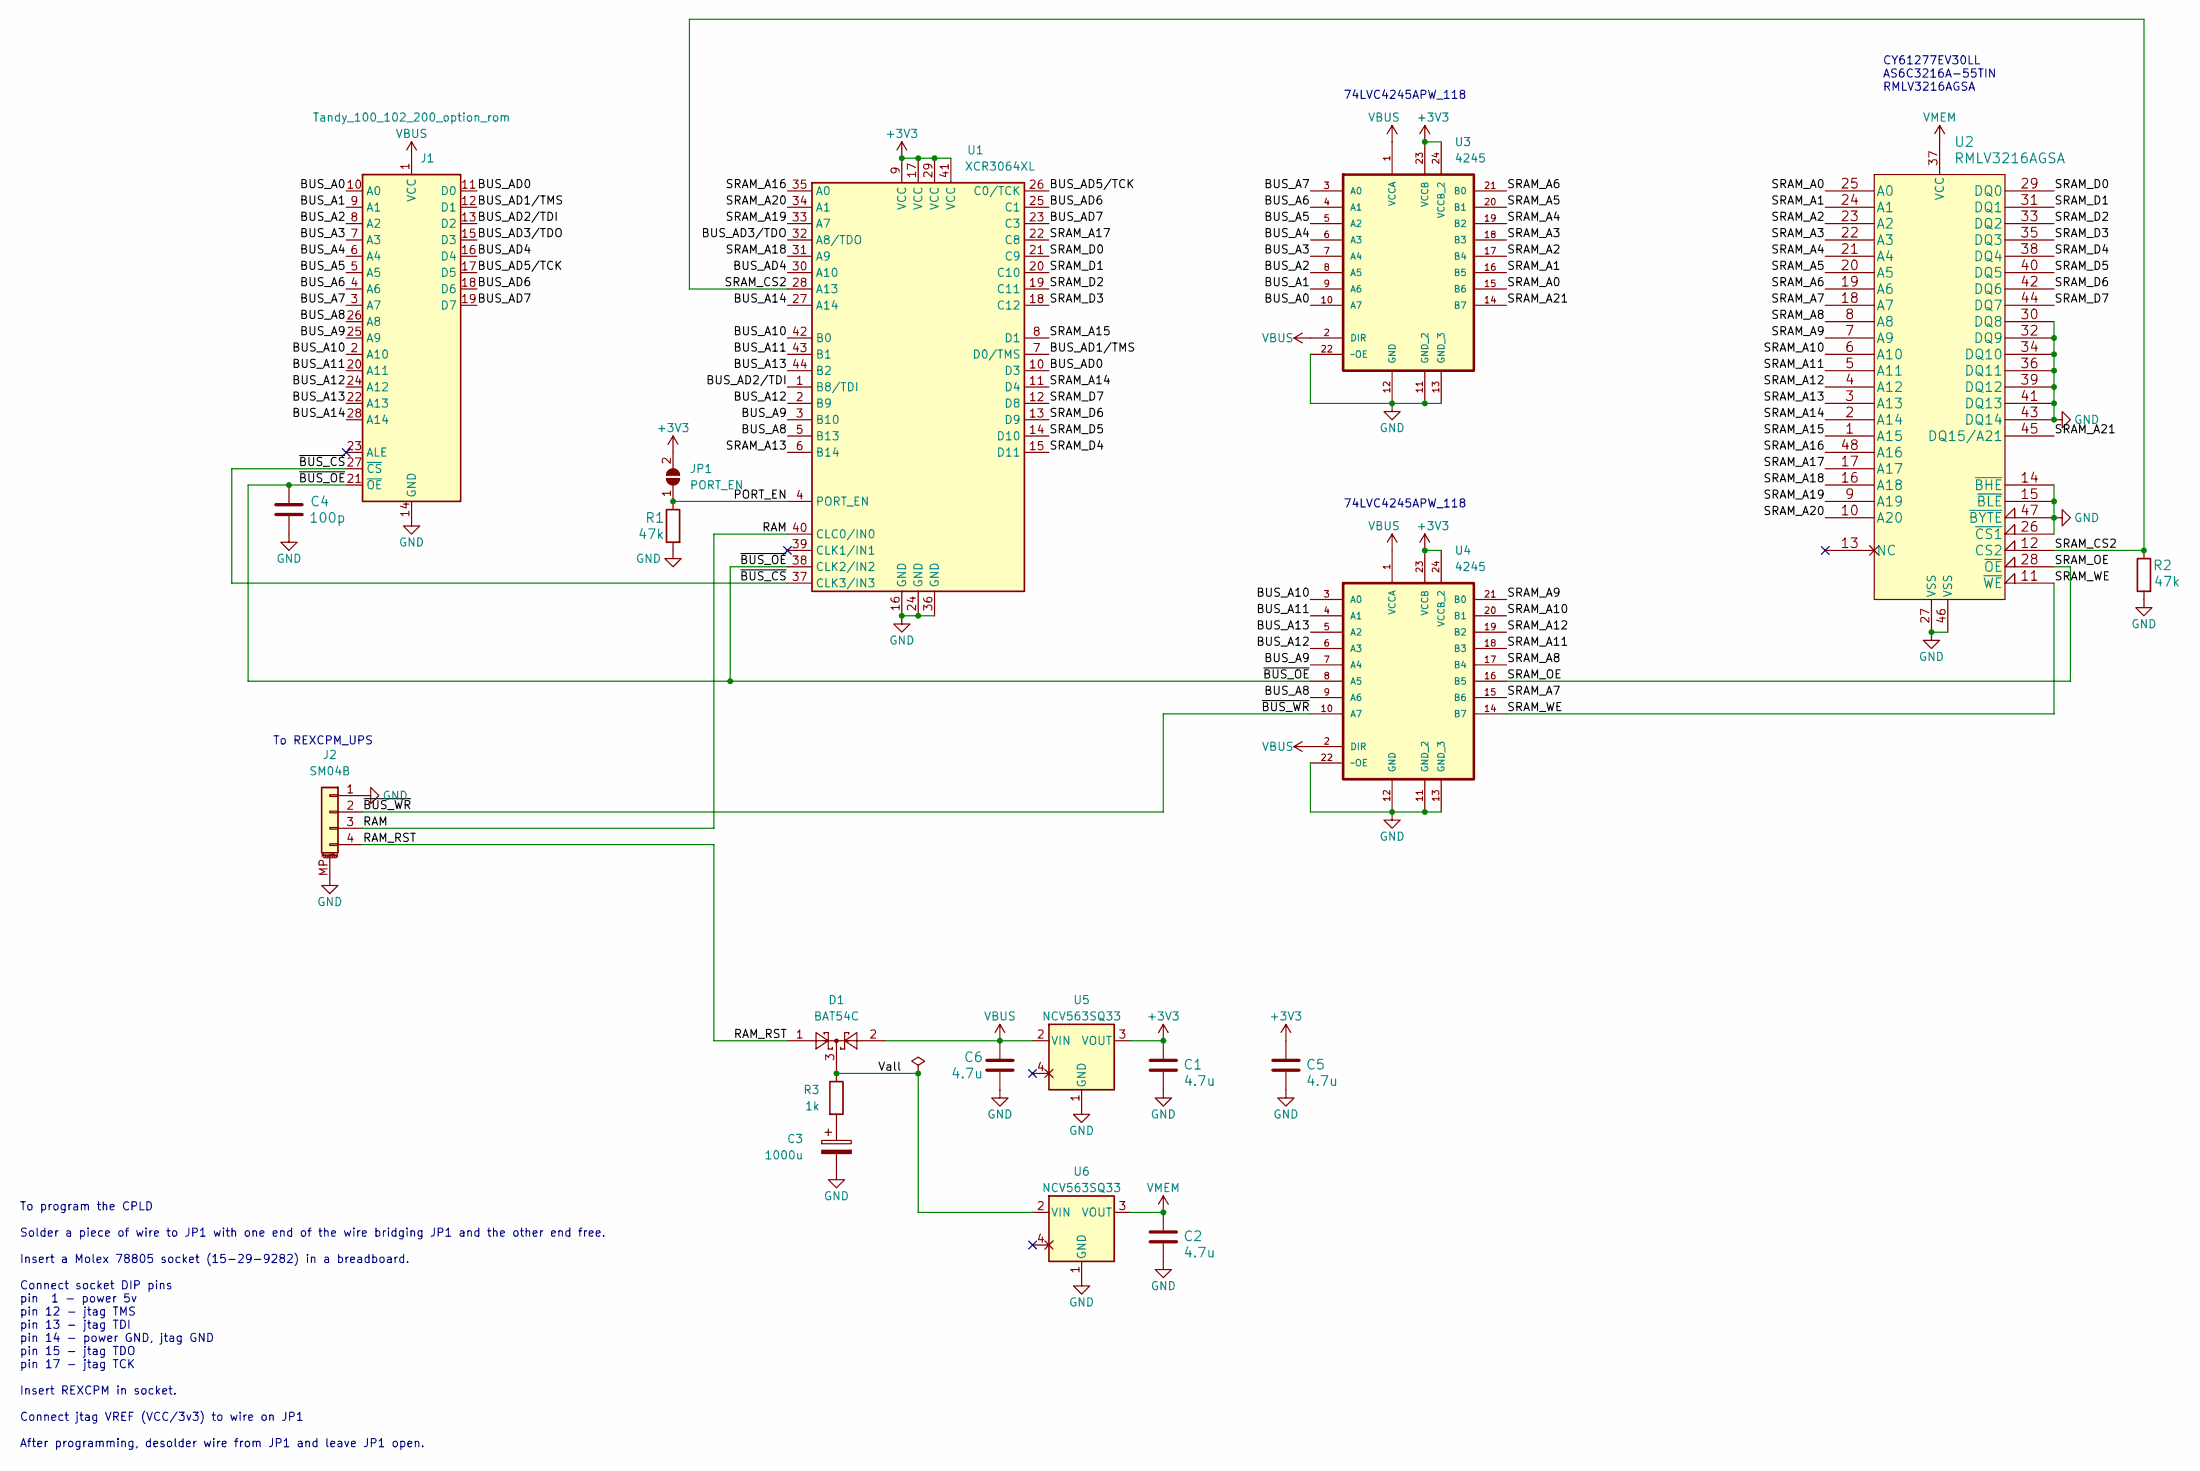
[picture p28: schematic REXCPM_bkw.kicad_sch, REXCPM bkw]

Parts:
C1, C2, C5, C6: 4.7u; C_0805
C3: 1000u; CP_7343-43
C4: 100p; C_0805
D1: BAT54C; SOT-23
J1: Tandy_100_102_200_option_rom; Molex78802_PCB_28_slots
J2: SM04B; JST_SH_SM04B-SRSS-TB_1x04-1MP_P1.00mm_Horizontal
JP1: PORT_EN; SolderJumper_1mm_2p_open
R1, R2: 47k; R_0805
R3: 1k; R_0805
U1: XCR3064XL; VQFP44
U2: RMLV3216AGSA; TSOP-48
U3, U4: 4245; TSSOP-24_4.4x7.8mm_P0.65mm
U5, U6: NCV563SQ33; SC-82AB

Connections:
+3V3: C1.1, C5.1, JP1.2 (B), U1.9 (VCC), U1.17 (VCC), U1.29 (VCC), U1.41 (VCC), U3.23 (VCCB), U3.24 (VCCB_2), U4.23 (VCCB), U4.24 (VCCB_2), U5.3 (VOUT)
+VSW: D1.3, R3.1, U6.2 (VIN)
/BUS_A0: J1.10 (A0), U3.10 (A7)
/BUS_A1: J1.9 (A1), U3.9 (A6)
/BUS_A2: J1.8 (A2), U3.8 (A5)
/BUS_A3: J1.7 (A3), U3.7 (A4)
/BUS_A4: J1.6 (A4), U3.6 (A3)
/BUS_A5: J1.5 (A5), U3.5 (A2)
/BUS_A6: J1.4 (A6), U3.4 (A1)
/BUS_A7: J1.3 (A7), U3.3 (A0)
/BUS_A8: J1.26 (A8), U1.5 (B13), U4.9 (A6)
/BUS_A9: J1.25 (A9), U1.3 (B10), U4.7 (A4)
/BUS_A10: J1.2 (A10), U1.42 (B0), U4.3 (A0)
/BUS_A11: J1.20 (A11), U1.43 (B1), U4.4 (A1)
/BUS_A12: J1.24 (A12), U1.2 (B9), U4.6 (A3)
/BUS_A13: J1.22 (A13), U1.44 (B2), U4.5 (A2)
/BUS_A14: J1.28 (A14), U1.27 (A14)
/BUS_AD0: J1.11 (D0), U1.10 (D3)
/BUS_AD1/TMS: J1.12 (D1), U1.7 (D0/TMS)
/BUS_AD2/TDI: J1.13 (D2), U1.1 (B8/TDI)
/BUS_AD3/TDO: J1.15 (D3), U1.32 (A8/TDO)
/BUS_AD4: J1.16 (D4), U1.30 (A10)
/BUS_AD5/TCK: J1.17 (D5), U1.26 (C0/TCK)
/BUS_AD6: J1.18 (D6), U1.25 (C1)
/BUS_AD7: J1.19 (D7), U1.23 (C3)
/PORT_EN: JP1.1 (A), R1.1, U1.4 (PORT_EN)
/RAM: J2.3, U1.40 (CLC0/IN0)
/RAM_RST: D1.1, J2.4
/SRAM_A0: U2.25 (A0), U3.15 (B6)
/SRAM_A1: U2.24 (A1), U3.16 (B5)
/SRAM_A2: U2.23 (A2), U3.17 (B4)
/SRAM_A3: U2.22 (A3), U3.18 (B3)
/SRAM_A4: U2.21 (A4), U3.19 (B2)
/SRAM_A5: U2.20 (A5), U3.20 (B1)
/SRAM_A6: U2.19 (A6), U3.21 (B0)
/SRAM_A7: U2.18 (A7), U4.15 (B6)
/SRAM_A8: U2.8 (A8), U4.17 (B4)
/SRAM_A9: U2.7 (A9), U4.21 (B0)
/SRAM_A10: U2.6 (A10), U4.20 (B1)
/SRAM_A11: U2.5 (A11), U4.18 (B3)
/SRAM_A12: U2.4 (A12), U4.19 (B2)
/SRAM_A13: U1.6 (B14), U2.3 (A13)
/SRAM_A14: U1.11 (D4), U2.2 (A14)
/SRAM_A15: U1.8 (D1), U2.1 (A15)
/SRAM_A16: U1.35 (A0), U2.48 (A16)
/SRAM_A17: U1.22 (C8), U2.17 (A17)
/SRAM_A18: U1.31 (A9), U2.16 (A18)
/SRAM_A19: U1.33 (A7), U2.9 (A19)
/SRAM_A20: U1.34 (A1), U2.10 (A20)
/SRAM_A21: U2.45 (DQ15/A21), U3.14 (B7)
/SRAM_CS2: R2.1, U1.28 (A13), U2.12 (CS2)
/SRAM_D0: U1.21 (C9), U2.29 (DQ0)
/SRAM_D1: U1.20 (C10), U2.31 (DQ1)
/SRAM_D2: U1.19 (C11), U2.33 (DQ2)
/SRAM_D3: U1.18 (C12), U2.35 (DQ3)
/SRAM_D4: U1.15 (D11), U2.38 (DQ4)
/SRAM_D5: U1.14 (D10), U2.40 (DQ5)
/SRAM_D6: U1.13 (D9), U2.42 (DQ6)
/SRAM_D7: U1.12 (D8), U2.44 (DQ7)
/SRAM_OE: U2.28 (~OE), U4.16 (B5)
/SRAM_WE: U2.11 (~WE), U4.14 (B7)
/~BUS_CS: J1.27 (~CS), U1.37 (CLK3/IN3)
/~BUS_OE: C4.1, J1.21 (~OE), U1.38 (CLK2/IN2), U4.8 (A5)
/~BUS_WR: J2.2, U4.10 (A7)
GND: C1.2, C2.2, C3.2, C4.2, C5.2, C6.2, J1.14 (GND), J2.1, J2.MP (MountPin), R1.2, R2.2, U1.16 (GND), U1.24 (GND), U1.36 (GND), U2.14 (~BHE), U2.15 (~BLE), U2.26 (~CS1), U2.27 (VSS), U2.30 (DQ8), U2.32 (DQ9), U2.34 (DQ10), U2.36 (DQ11), U2.39 (DQ12), U2.41 (DQ13), U2.43 (DQ14), U2.46 (VSS), U2.47 (~BYTE), U3.11 (GND_2), U3.12 (GND), U3.13 (GND_3), U3.22 (~OE), U4.11 (GND_2), U4.12 (GND), U4.13 (GND_3), U4.22 (~OE), U5.1 (GND), U6.1 (GND)
unnamed: C3.1, R3.2
VBUS: C6.1, D1.2, J1.1 (VCC), U3.1 (VCCA), U3.2 (DIR), U4.1 (VCCA), U4.2 (DIR), U5.2 (VIN)
VMEM: C2.1, U2.37 (VCC), U6.3 (VOUT)

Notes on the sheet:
To program the CPLD Solder a piece of wire to JP1 with one end of the wire bridging JP1 and the other end free. Insert a Molex 78805 socket (15-29-9282) in a breadboard. Connect socket DIP pins pin 1 - power 5v pin 12 - jtag TMS pin 13 - jtag TDI pin 14 - power GND, jtag GND pin 15 - jtag TDO pin 1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
74LVC4245APW_118
To REXCPM_UPS
CY61277EV30LL AS6C3216A-55TIN RMLV3216AGSA

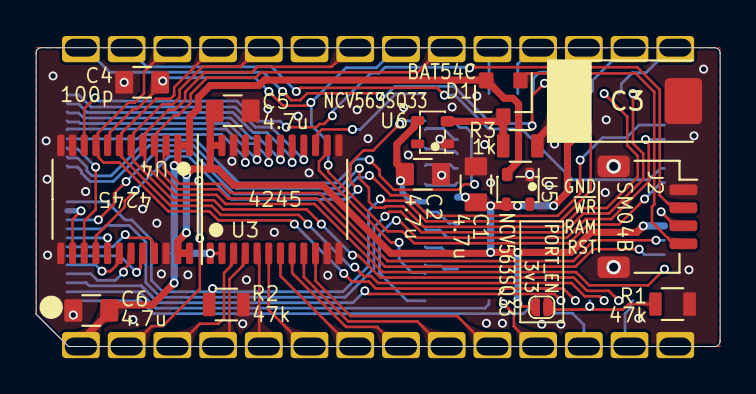
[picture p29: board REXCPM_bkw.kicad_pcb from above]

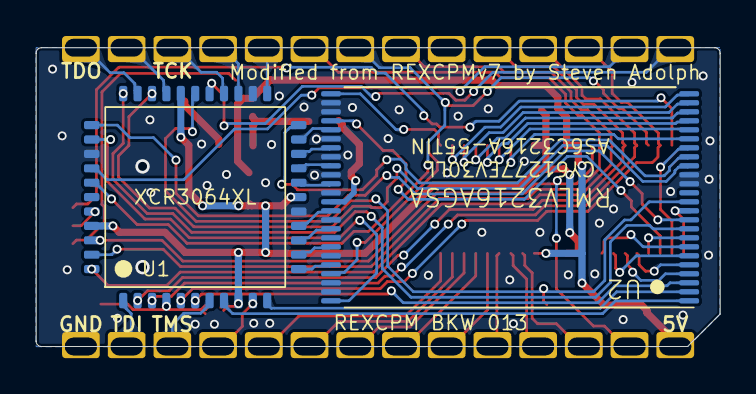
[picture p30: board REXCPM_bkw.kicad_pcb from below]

Board: 2 copper layers, 38.0 x 16.6 mm, 19 parts (2 on the bottom side), 68 nets.

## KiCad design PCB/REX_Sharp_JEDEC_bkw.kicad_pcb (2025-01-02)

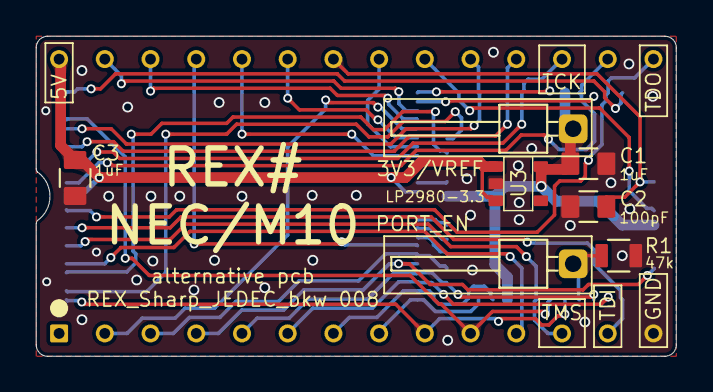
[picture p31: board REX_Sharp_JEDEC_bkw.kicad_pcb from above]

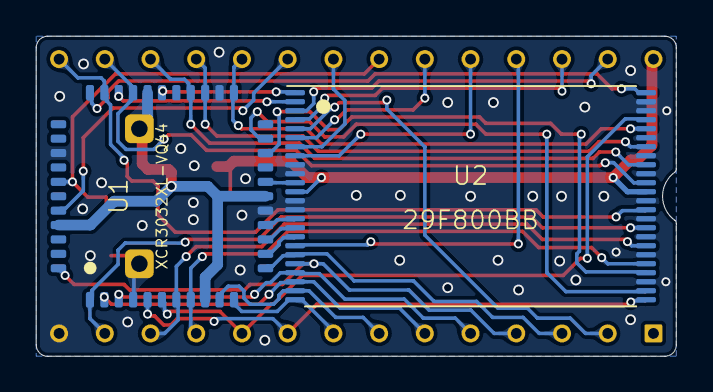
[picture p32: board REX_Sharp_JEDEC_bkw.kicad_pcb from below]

Board: 2 copper layers, 35.6 x 17.8 mm, 10 parts (2 on the bottom side), 38 nets.

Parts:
C1, C3: 1uF; C_0805
C2: 100pF; C_0805
J1: Option-ROM SOCKET; DIP-28_600_pcb_shallow_notch
R1: 47k; R_0805
TP1: PORT_EN; 1x1_pin_h
TP2: 3V3/VREF; 1x1_pin_h
U1: XCR3032XL-VQ44; VQFP44
U2: 29F800BB; TSOP-48
U3: LP2980-3.3; SOT-23-5

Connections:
+3V3: C1.1, TP2.1, U1.9 (VCC), U1.17 (VCC), U1.29 (VCC), U1.41 (VCC), U3.5 (VOUT)
+5V: C3.1, J1.28 (VCC), U2.12 (~RESET), U2.37 (VCC), U3.1 (VIN), U3.3 (EN)
/A0: J1.10 (A0), U1.6 (B14), U2.45 (DQ15/A-1)
/A1: J1.9 (A1), U1.5 (B13), U2.25 (A0)
/A2: J1.8 (A2), U1.11 (D4), U2.24 (A1)
/A3: J1.7 (A3), U1.10 (D3), U2.23 (A2)
/A4: J1.6 (A4), U1.2 (B9), U2.22 (A3)
/A5: J1.5 (A5), U1.3 (B10), U2.21 (A4)
/A6: J1.4 (A6), U1.44 (B2), U2.20 (A5)
/A7: J1.3 (A7), U1.12 (D8), U2.19 (A6)
/A8: J1.25 (A8), U2.18 (A7)
/A9: J1.24 (A9), U2.8 (A8)
/A10: J1.21 (A10), U2.7 (A9)
/A11: J1.23 (A11), U2.6 (A10)
/A12: J1.2 (A12), U2.5 (A11)
/A13: J1.26 (A13), U2.4 (A12)
/A14: J1.27 (A14), U2.3 (A13)
/A15: U1.31 (A9), U2.2 (A14)
/A16: U1.28 (A13), U2.1 (A15)
/A17: U1.33 (A7), U2.48 (A16)
/A18: U1.13 (D9), U2.17 (A17)
/A19: U1.14 (D10), U2.16 (A18)
/D0: J1.11 (D0), U1.8 (D1), U2.29 (DQ0)
/D1/TMS: J1.12 (D1), U1.7 (D0/TMS), U2.31 (DQ1)
/D2/TDI: J1.13 (D2), U1.1 (B8/TDI), U2.33 (DQ2)
/D3/TDO: J1.15 (D3), U1.32 (A8/TDO), U2.35 (DQ3)
/D4: J1.16 (D4), U1.30 (A10), U2.38 (DQ4)
/D5/TCK: J1.17 (D5), U1.26 (C0/TCK), U2.40 (DQ5)
/D6: J1.18 (D6), U1.25 (C1), U2.42 (DQ6)
/D7: J1.19 (D7), U1.23 (C3), U2.44 (DQ7)
/PORT_EN: R1.2, TP1.1, U1.4 (PORT_EN)
/RY/~BY: U1.15 (D11), U2.15 (RY/~BY)
/~BUS_CS: J1.20 (~CE), U1.40 (CLC0/IN0)
/~BUS_OE: C2.1, J1.22 (~OE), U1.38 (CLK2/IN2)
/~SRAM_CE: U1.21 (C9), U2.26 (~CE)
/~SRAM_OE: U1.20 (C10), U2.28 (~OE)
/~SRAM_WE: U1.18 (C12), U2.11 (~WE)
GND: C1.2, C2.2, C3.2, J1.14 (GND), R1.1, U1.16 (GND), U1.24 (GND), U1.36 (GND), U2.9 (NC(A19)), U2.10 (NC), U2.13 (NC), U2.14 (NC), U2.27 (VSS), U2.30 (DQ8), U2.32 (DQ9), U2.34 (DQ10), U2.36 (DQ11), U2.39 (DQ12), U2.41 (DQ13), U2.43 (DQ14), U2.46 (VSS), U2.47 (~BYTE), U3.2 (GND)

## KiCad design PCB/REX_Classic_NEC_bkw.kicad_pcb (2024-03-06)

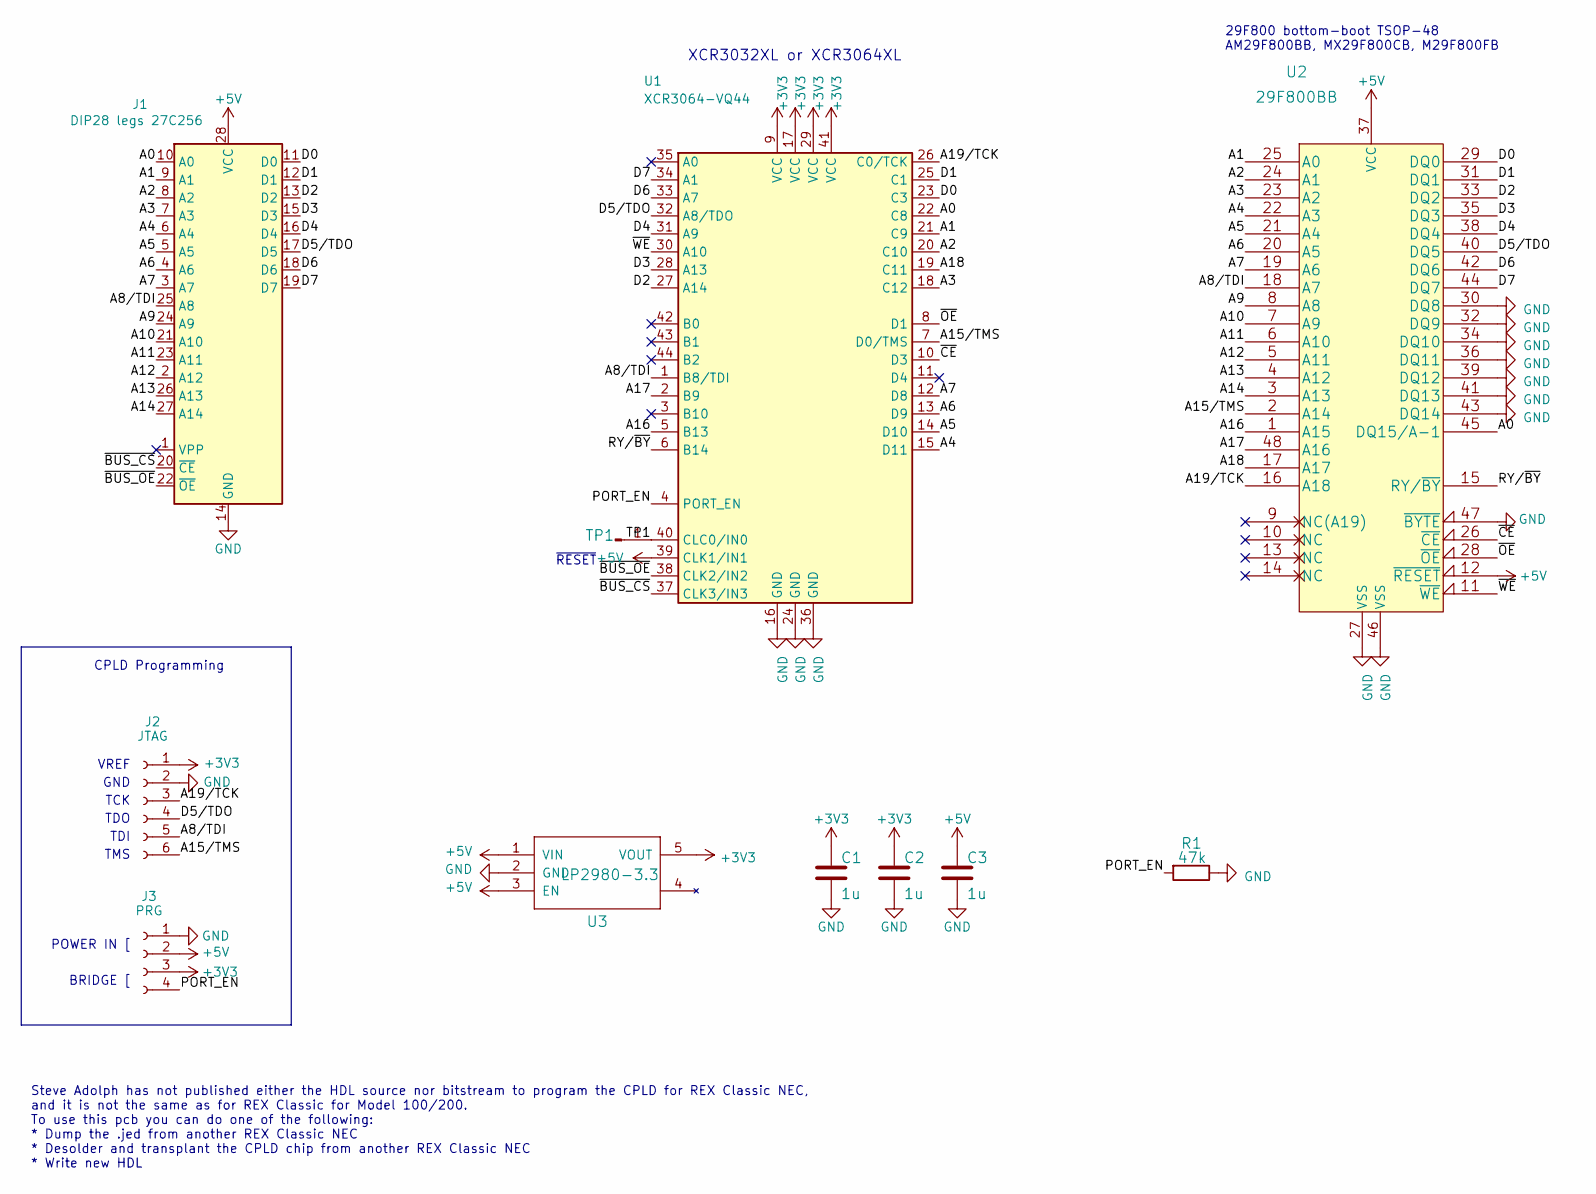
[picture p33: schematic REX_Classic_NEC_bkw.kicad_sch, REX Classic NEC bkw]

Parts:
C1, C2, C3: 1u; C_0805
J1: DIP28 legs 27C256; DIP-28_600_pcb_shallow_notch
J2: JTAG; 1x6_pcb_socket
J3: PRG; 1x4_pcb_socket
R1: 47k; R_0805
TP1: PINHD-1X1; 1x1_pin_h
U1: XCR3064-VQ44; VQFP44
U2: 29F800BB; TSOP-48
U3: LP2980-3.3; SOT-23-5

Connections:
+3V3: C1.1, C2.1, J2.1, J3.3, U1.9 (VCC), U1.17 (VCC), U1.29 (VCC), U1.41 (VCC), U3.5 (VOUT)
+5V: C3.1, J1.28 (VCC), J3.2, U1.39 (CLK1/IN1), U2.12 (~RESET), U2.37 (VCC), U3.1 (VIN), U3.3 (EN)
/A0: J1.10 (A0), U1.22 (C8), U2.45 (DQ15/A-1)
/A1: J1.9 (A1), U1.21 (C9), U2.25 (A0)
/A2: J1.8 (A2), U1.20 (C10), U2.24 (A1)
/A3: J1.7 (A3), U1.18 (C12), U2.23 (A2)
/A4: J1.6 (A4), U1.15 (D11), U2.22 (A3)
/A5: J1.5 (A5), U1.14 (D10), U2.21 (A4)
/A6: J1.4 (A6), U1.13 (D9), U2.20 (A5)
/A7: J1.3 (A7), U1.12 (D8), U2.19 (A6)
/A8/TDI: J1.25 (A8), J2.5, U1.1 (B8/TDI), U2.18 (A7)
/A9: J1.24 (A9), U2.8 (A8)
/A10: J1.21 (A10), U2.7 (A9)
/A11: J1.23 (A11), U2.6 (A10)
/A12: J1.2 (A12), U2.5 (A11)
/A13: J1.26 (A13), U2.4 (A12)
/A14: J1.27 (A14), U2.3 (A13)
/A15/TMS: J2.6, U1.7 (D0/TMS), U2.2 (A14)
/A16: U1.5 (B13), U2.1 (A15)
/A17: U1.2 (B9), U2.48 (A16)
/A18: U1.19 (C11), U2.17 (A17)
/A19/TCK: J2.3, U1.26 (C0/TCK), U2.16 (A18)
/D0: J1.11 (D0), U1.23 (C3), U2.29 (DQ0)
/D1: J1.12 (D1), U1.25 (C1), U2.31 (DQ1)
/D2: J1.13 (D2), U1.27 (A14), U2.33 (DQ2)
/D3: J1.15 (D3), U1.28 (A13), U2.35 (DQ3)
/D4: J1.16 (D4), U1.31 (A9), U2.38 (DQ4)
/D5/TDO: J1.17 (D5), J2.4, U1.32 (A8/TDO), U2.40 (DQ5)
/D6: J1.18 (D6), U1.33 (A7), U2.42 (DQ6)
/D7: J1.19 (D7), U1.34 (A1), U2.44 (DQ7)
/PORT_EN: J3.4, R1.2, U1.4 (PORT_EN)
/RY/~BY: U1.6 (B14), U2.15 (RY/~BY)
/TP1: TP1.1, U1.40 (CLC0/IN0)
/~BUS_CS: J1.20 (~CE), U1.37 (CLK3/IN3)
/~BUS_OE: J1.22 (~OE), U1.38 (CLK2/IN2)
/~CE: U1.10 (D3), U2.26 (~CE)
/~OE: U1.8 (D1), U2.28 (~OE)
/~WE: U1.30 (A10), U2.11 (~WE)
GND: C1.2, C2.2, C3.2, J1.14 (GND), J2.2, J3.1, R1.1, U1.16 (GND), U1.24 (GND), U1.36 (GND), U2.27 (VSS), U2.30 (DQ8), U2.32 (DQ9), U2.34 (DQ10), U2.36 (DQ11), U2.39 (DQ12), U2.41 (DQ13), U2.43 (DQ14), U2.46 (VSS), U2.47 (~BYTE), U3.2 (GND)

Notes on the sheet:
TCK
POWER IN [
TMS
GND
~{RESET}
TDO
BRIDGE [
TDI
29F800 bottom-boot TSOP-48 AM29F800BB, MX29F800CB, M29F800FB
XCR3032XL or XCR3064XL
VREF
CPLD Programming
Steve Adolph has not published either the HDL source nor bitstream to program the CPLD for REX Classic NEC, and it is not the same as for REX Classic for Model 100/200. To use this pcb you can do one of the following: * Dump the .jed from another REX Classic NEC * Desolder and transplant the CPLD c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

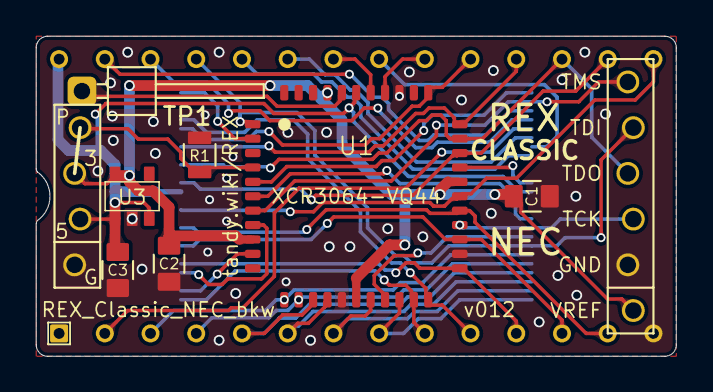
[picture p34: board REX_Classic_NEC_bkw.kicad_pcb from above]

Board: 2 copper layers, 35.6 x 17.8 mm, 11 parts (1 on the bottom side), 39 nets.

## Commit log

2018-04-29 Original Commit Original source was Rex.brd from REX_STD.zip from Steve Adolph on Club100.org Rex.brd was an EagleCAD file, but not recognized/importable/convertable by any utils at this time. Rex.br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
    [REX1.kicad_pcb]
2019-09-12 initial commit bkw c11 version
    [REX1.kicad_pcb, REX1_bkw.kicad_pcb, REX1_bkw.sch]
2020-02-05 slightly reduced outside dimensions or 3d print variability
    [REX1_bkw.kicad_pcb]
2020-02-06 reduce X & Y for 3d printing variability
    [REX1_bkw.kicad_pcb, REX1_bkw.sch]
2020-02-20 nonsense trace nudging
    [REX1_bkw.kicad_pcb]
2020-02-20 initial NEC 8201a version
    [REX1_NEC_bkw.kicad_pcb, REX1_NEC_bkw.sch]
2020-02-20 move TP1 & TP2 pins so dupont connector fits better between cpld and socket
    [REX1_bkw.kicad_pcb]
2020-02-21 correct silkscreen leadframe part#
    [REX1_NEC_bkw.kicad_pcb]
2020-02-29 update to latest pcb2molex8878 carrier and pcb outline
    [REX1_bkw.kicad_pcb]
2020-03-24 8201 v2 using freerouting autorouter followed by manual fixups
    [REX1_NEC_bkw.kicad_pcb, REX1_NEC_bkw.sch, REX_8201_bkw.kicad_pcb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]
2020-06-10 remove some sharp inside angles. move c1 on nec.
    [REX_NEC_bkw.kicad_pcb, REX_bkw.kicad_pcb]
2020-12-01 flip ram and reroute nec board, several other minor touches both boards
    [REX_NEC_bkw.kicad_pcb, REX_NEC_bkw.sch, REX_NEC_bkw_001.kicad_pcb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]
2020-12-01 larger vias for cheaper manufacturing
    [REX_Classic_BKW_re-spin.BOM.csv, REX_NEC_bkw.kicad_pcb, REX_bkw.kicad_pcb]
2021-03-08 Less expensive manufacturing tolerances. Rename to REX Classic.
    [REX_Classic_bkw.BOM.csv, REX_Classic_bkw.kicad_pcb, REX_Classic_bkw.sch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]
2021-03-15 min drill 0.3mm for PCBWAY, replace GND traces with zone fill
    [REX_Classic_bkw.BOM.csv, REX_Classic_bkw.kicad_pcb, REX_Classic_bkw.sch]
2021-05-23 upgrade board outline and carrier to v004
    [REX_Classic_bkw.kicad_pcb, REX_Classic_bkw.sch, REX_NEC_bkw.kicad_pcb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]
2021-07-05 remove pointless busses from sch, minor silkscreen tweaks
    [REX_Classic_bkw.kicad_pcb, REX_Classic_bkw.sch]
2021-07-07 clearance around some traces & vias
    [REX_Classic_bkw.kicad_pcb]
2021-07-08 clearances, remove pointless busses in schematic
    [REX_Classic_bkw.kicad_pcb, REX_Classic_bkw.sch, REX_NEC_bkw.kicad_pcb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]
2022-09-07 v024, 0.2mm spaces, thicker power traces
    [REX_Classic_NEC_bkw.kicad_pcb, REX_Classic_NEC_bkw.kicad_sch, REX_Classic_NEC_bkw_alternate_routing.kicad_pcb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]
2023-07-04 kicad 7, 0.2mm tracks, 0.3x0.5mm vias, add caps on 3v3
    [REX_Classic_NEC_bkw.kicad_pcb, REX_Classic_bkw.BOM.csv, REX_Classic_bkw.kicad_pcb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]
2023-07-04 min text/line sizes in some footprints
    [REX_Classic_bkw.kicad_pcb]
2023-07-05 small layout nudges
    [REX_Classic_NEC_bkw.kicad_pcb, REX_Classic_NEC_bkw_alternate_routing.kicad_pcb]
2023-10-09 streamline rexcpm routing
    [REXCPM_bkw.kicad_pcb]
2023-11-06 rexcpm small layout opts
    [REXCPM_bkw.kicad_pcb, REXCPM_bkw.kicad_sch]
2023-11-06 rexcpm qwiic connector
    [REXCPM_bkw.kicad_pcb, REXCPM_bkw.kicad_sch]
2023-11-06 rexcpm add cap on vbus
    [REXCPM_bkw.kicad_pcb, REXCPM_bkw.kicad_sch]
2023-11-08 reorganize repo files
    [REXCPM_bkw.kicad_pcb, REXCPM_bkw.kicad_sch, REX_Classic_NEC_bkw.kicad_pcb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]
2024-03-06 carrier 3d model and kicad 8
    [REXCPM_bkw.kicad_pcb, REXCPM_bkw.kicad_sch, REX_Classic_NEC_bkw.kicad_pcb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]
2024-03-23 0805 footprints, minor trace adjustments
    [REX_Classic_bkw.kicad_pcb]
2024-03-23 plot settings
    [REX_Classic_bkw.kicad_pcb]
2024-07-21 vhdl: comment unused pin in ucf, xise project file for build settings, actually builds
2025-01-02 add sharp-tandy
    [REX_Sharp_JEDEC_bkw.kicad_pcb, REX_Sharp_JEDEC_bkw.kicad_sch, REX_Sharp_TANDY_bkw.kicad_pcb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]
2025-02-01 remove dead shapeways url for carrier
    [REX_Classic_bkw.BOM.csv, REX_Classic_bkw.kicad_pcb, REX_Classic_bkw.kicad_sch]
2026-08-17 housing component, fillet tracks, molex datasheets corrections
    [REXCPM_bkw.kicad_pcb, REX_Classic_bkw.kicad_pcb, REX_Classic_bkw.kicad_sch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]
